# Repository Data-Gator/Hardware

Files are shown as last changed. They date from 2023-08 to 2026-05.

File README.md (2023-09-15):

# Hardware
Documents how to build and use Data Gator boards.

| Resource | Description |
| :---: | :---: |
| [Hardware Revision Design Files](./Hardware_Revisions/README.md) | Links to board design files for v1.4 and later. Contains electrical design schematics, BOMs, CAD, and assembly automation files. |
| [Sensors and Wiring Guides](./Sensors_And_Wiring/README.md) | Links to guides for using various supported sensors with the Data Gators. |
| [Board Fabrication and Assembly Guides](./Board_Assembly_Guides/README.md) | Documentation for self-assembly of surface mount and through-hole components for the Data Gators. |

## Hardware Overview

The images below show various components incorporated into the Data Gator carrier board design. 

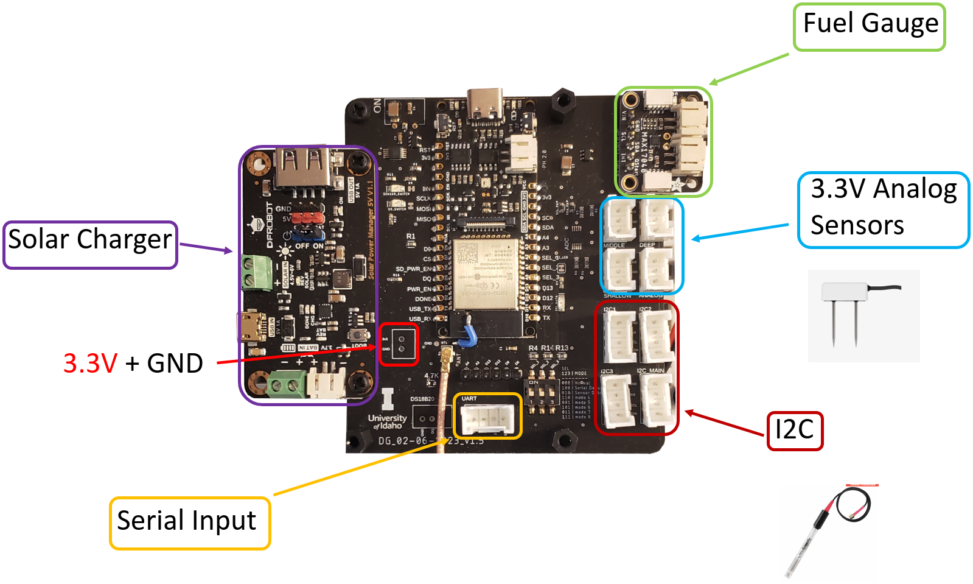
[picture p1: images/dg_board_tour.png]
board tour


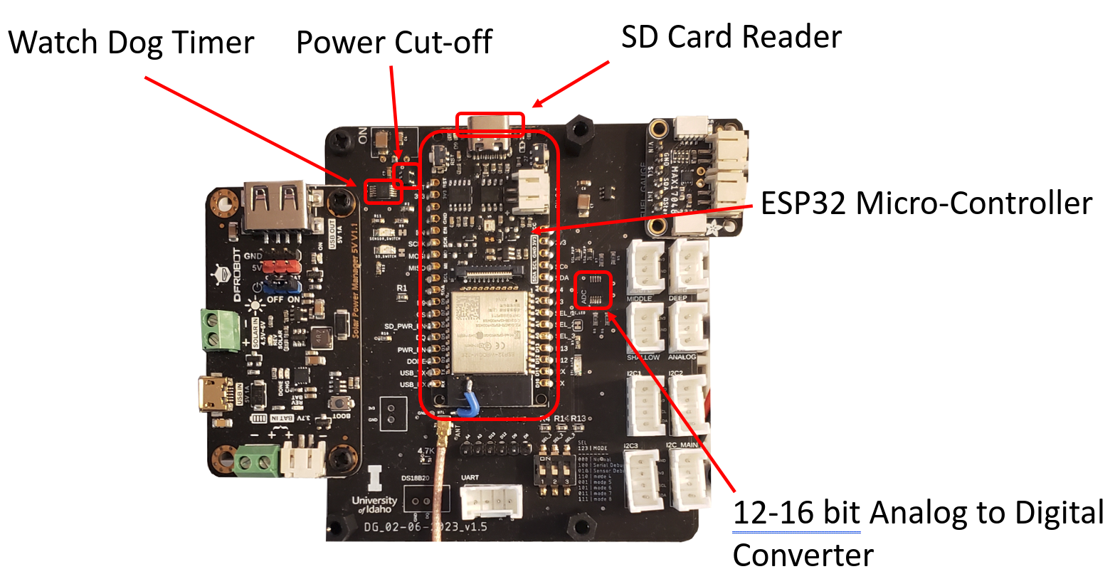
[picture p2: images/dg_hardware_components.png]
hardware comp


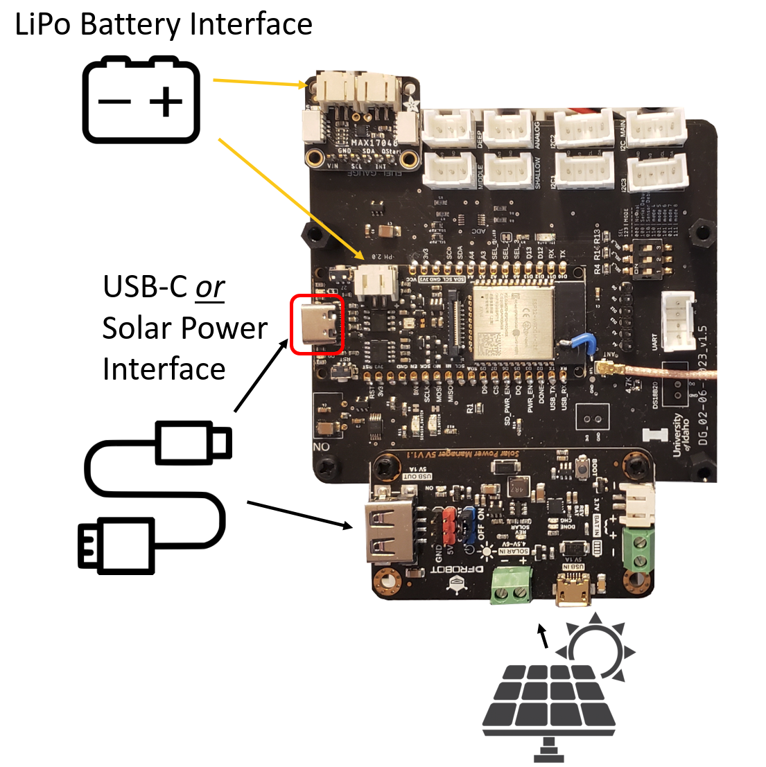
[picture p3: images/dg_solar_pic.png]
solar hookups


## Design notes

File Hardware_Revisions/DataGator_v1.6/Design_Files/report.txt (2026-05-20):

Info: Processing symbol 'R10:Resistor_SMD:R_0603_1608Metric'.
Info: Processing symbol 'C1:Capacitor_SMD:C_1210_3225Metric'.
Info: Processing symbol 'JP2:Connector_PinHeader_2.54mm:PinHeader_1x06_P2.54mm_Vertical'.
Info: Processing symbol 'JP3:'.
Info: Processing symbol 'JP4:Jumper:SolderJumper-2_P1.3mm_Open_RoundedPad1.0x1.5mm'.
Info: Processing symbol 'R1:Resistor_SMD:R_0603_1608Metric'.
Info: Processing symbol 'R2:Resistor_SMD:R_0603_1608Metric'.
Info: Processing symbol 'R3:Resistor_SMD:R_0603_1608Metric'.
Info: Processing symbol 'R4:Resistor_SMD:R_0603_1608Metric'.
Info: Processing symbol 'R5:Resistor_SMD:R_0603_1608Metric'.
Info: Processing symbol 'R6:Resistor_SMD:R_0603_1608Metric'.
Info: Processing symbol 'R7:Resistor_SMD:R_0603_1608Metric'.
Info: Processing symbol 'R8:Resistor_SMD:R_0603_1608Metric'.
Info: Processing symbol 'R9:Resistor_SMD:R_0603_1608Metric'.
Info: Processing symbol 'JP1:'.
Info: Processing symbol 'R11:Resistor_SMD:R_0603_1608Metric'.
Info: Processing symbol 'R12:Resistor_SMD:R_0603_1608Metric'.
Info: Processing symbol 'R13:Resistor_SMD:R_0603_1608Metric'.
Info: Processing symbol 'R14:'.
Info: Processing symbol 'R15:'.
Info: Processing symbol 'S1:MSS-102568-14A-90-D:SW_MSS-102568-14A-90-D'.
Info: Processing symbol 'S2:DS04_254_2_03BK_SMT:SW_DS04-254-2-03BK-SMT'.
Info: Processing symbol 'U1:footprints:SOT25_DIO'.
Info: Processing symbol 'U2:footprints:SOT25_DIO'.
Info: Processing symbol 'U3:TPL5000DGST:SOP50P490X110-10N'.
Info: Processing symbol 'U4:DFR0654:MODULE_DFR0654'.
Info: Processing symbol 'U5:ADS1015IDGST:SOP50P490X110-10N'.
Info: Processing symbol 'J8:533750310:MOLEX_533750310'.
Info: Processing symbol 'C2:Capacitor_SMD:C_0603_1608Metric'.
Info: Processing symbol 'C3:Capacitor_SMD:C_0603_1608Metric'.
Info: Processing symbol 'C4:Capacitor_SMD:C_0603_1608Metric'.
Info: Processing symbol 'C5:Capacitor_SMD:C_1210_3225Metric'.
Info: Processing symbol 'C6:Capacitor_SMD:C_0603_1608Metric'.
Info: Processing symbol 'D1:LED_SMD:LED_1206_3216Metric'.
Info: Processing symbol 'D2:LED_SMD:LED_1206_3216Metric'.
Info: Processing symbol 'J3:Connector_Coaxial:U.FL_Hirose_U.FL-R-SMT-1_Vertical'.
Info: Processing symbol 'J4:MEM2051-00-195-00-A_REVD1:GCT_MEM2051-00-195-00-A_REVD1'.
Info: Processing symbol 'J5:533750310:MOLEX_533750310'.
Info: Processing symbol 'J6:533750310:MOLEX_533750310'.
Info: Processing symbol 'J7:533750310:MOLEX_533750310'.
Info: Processing symbol 'J9:533750410:MOLEX_533750410'.
Info: Processing symbol 'J10:533750410:MOLEX_533750410'.
Info: Processing symbol 'J11:533750410:MOLEX_533750410'.
Info: Processing symbol 'J12:533750410:MOLEX_533750410'.
Info: Processing symbol 'J13:533750210:MOLEX_533750210'.
Info: Processing symbol 'J14:533750310:MOLEX_533750310'.
Info: Processing symbol 'J15:Connector_PinHeader_2.54mm:PinHeader_1x06_P2.54mm_Vertical'.
Info: Processing symbol 'J16:533750410:MOLEX_533750410'.
Add J16 (footprint '533750410:MOLEX_533750410').
Add J9 (footprint '533750410:MOLEX_533750410').
Add J10 (footprint '533750410:MOLEX_533750410').
Add J11 (footprint '533750410:MOLEX_533750410').
Add S1 (footprint 'MSS-102568-14A-90-D:SW_MSS-102568-14A-90-D').
Add J12 (footprint '533750410:MOLEX_533750410').

Info: Total warnings: 0, errors: 0.

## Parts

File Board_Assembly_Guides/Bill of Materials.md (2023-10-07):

# Bill Of Materials
## Surface Mount Devices (SMD)
This is a list of devices and quantities which should be purchased for building the Data Gator. PCB Fabrication companies may do the purchasing or use company stock.

| Name | Description | Quantity |Digikey/Mouser Part # | Link | 
| :---: | :---: | :---: | :---: | :---: |
| Resistor | 0603 100kOhm| 11 || https://www.digikey.com/en/products/detail/walsin-technology-corporation/WR06X104-JTL/13241355 |
| Ceramic Capacitor |10uF| 2 || https://www.digikey.com/en/products/detail/samsung-electro-mechanics/CL32A106MOJNNNE/3888522 |
| Resistor | 0603 2kOhm| 3 || https://www.digikey.com/en/products/detail/yageo/RC0603FR-072KL/727009 | 
| Resistor | 0603 5kOhm| 2 || https://www.digikey.com/en/products/detail/yageo/RT0603BRE075KL/7708365 | 
| Resistor | 0603 4.7kOhm | 2 || https://www.digikey.com/en/products/detail/yageo/RC0603FR-074K7L/727212 | 
| Micro-SD Card Holder | 9 Position, Push-Push, Right Angle | 1 || https://www.digikey.com/en/products/detail/gct/MEM2051-00-195-00-A/10460360?s=N4IgTCBcDaILIFE5gAwFYCMIC6BfIA | 
| u.FL SMT| 50 Ohm | 1 || https://www.digikey.com/en/products/detail/hirose-electric-co-ltd/U-FL-R-SMT-1-40/4285474 | 
| DIP Switch | SPST, 2.54mm, 3 position |1 || https://www.digikey.com/en/products/detail/cui-devices/DS04-254-2-03BK-SMT/11310920 |
| ADS1015 (Analog-to-Digital Converter) | 12 bit, IDGST, 10VSSOP package| 1 || https://www.digikey.com/en/products/detail/texas-instruments/ADS1015IDGST/2174980 | 
| AP2171WG | IC Power Switch, P-Channel, SOT25 package|2|| https://www.digikey.com/en/products/detail/diodes-incorporated/AP2171WG-7/1964664 | 
| TPL5000| Watch Dog Timer, 10VSSOP package|1|| https://www.digikey.com/en/products/detail/texas-instruments/TPL5000DGST/4331549 | 
| Red LED | 1206, 20mA, 1.7V|3|| https://www.mouser.com/ProductDetail/Stanley-Electric/BR1101W-TR?qs=byeeYqUIh0Pp62ktTXSSvA%3D%3D |
| Ceramic Capacitor | 0603, 0.1uF|4|| https://www.mouser.com/ProductDetail/KEMET/C0603C104K5RAC3121?qs=oBCMsStVSxe1EkGyoyETtg%3D%3D |
# Through-Hole Components
These components, as well as the daughter boards, must be soldered or attached to the Data Gator.

| Name | Description | Quantity | Digikey/Mouser Part # | Link | 
| :---: | :---: | :---: | :---: | :---:|
| WDT Switch | SPDT slide switch, 1.4mm | 1 || https://www.digikey.com/en/products/detail/cui-devices/MSS-102568-14A-90-D/13978973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 |
| 6-pin header| 6 pin header, 2.54mm pitch | 1 || https://www.digikey.com/en/products/detail/adam-tech/PH1-06-UA/9830394 | 

# Daughter Boards

| Name | Description | Quantity | Digikey/Mouser Part # | Link | 
| :---: | :---: | :---: | :---: | :---: |
| Firebeetle3 ESP32-E | Espressif ESP-WROOM-32E based micro-controller board with USB interface and GPIO accessible through castellated vias. |1| | https://www.dfrobot.com/product-2195.html |
| Adafruit MAX17048 Fuel Gauge | LiPoly / LiIon Battery Monitor/Fuel Gauge |1| | https://www.adafruit.com/product/5580 | 
| DFRobot Solar Power Manager 5V | Manages solar charging for 5V LiPoly batteries. | 1| | https://www.dfrobot.com/product-1712.html |

# Connectors
Connectors must be soldered by hand since they are through-hole components. These are used to connect analog and I2C sensors to the board. Both sensor options are viable and represent two different price points. Buying 15 sets of connectors in February 2023, JST connectors cost $67 dollars total while Molex connectors cost $125.
### Molex Connectors
The premium option, likely more resistant to  physical damage and support more force if sensor wires get  pulled.

| Item | Quantity | Link | 
| :---: | :---: | :---: |
| 2 Pin Housing Receptacle, 2.5mm | 1 | https://www.digikey.com/en/products/detail/molex/0511030200/2405316
| 3 Pin Housing Receptacle, 2.5mm| 4 | https://www.digikey.com/en/products/detail/molex/0511030300/2405314
| 4 Pin Housing Receptacle, 2.5mm | 4| https://www.digikey.com/en/products/detail/molex/0511030400/2405335
| Socket Contact, 22-28 AWG Crimp | 30 | https://www.digikey.com/en/products/detail/molex/0503518000/2404938
| 2 Pin Connector Header, 2.5mm | 1 | https://www.digikey.com/en/products/detail/molex/0533750210/2405348
| 3 Pin Connector Header, 2.5mm | 4 | https://www.digikey.com/en/products/detail/molex/0533750310/3263194
| 4 Pin Connector Header, 2.5mm | 4 | https://www.digikey.com/en/products/detail/molex/0533750410/2421210

### JST Connectors

Cheaper than Molex connectors and functionally equivalent. The connection made is looser and may be more prone to failure under physical stress such as pulling.

| Item | Quantity | Link | 
| :---: | :---: | :---: |
| 2 Pin Connector Header, 2.5mm| 1 | https://www.digikey.com/en/products/detail/jst-sales-america-inc/B02B-XASK-1-LF-SN/1634730
| 3 Pin Connector Header, 2.5mm | 4 | https://www.digikey.com/en/products/detail/jst-sales-america-inc/B03B-XASK-1-LF-SN/1634731
| 4 Pin Connector Header, 2.5mm | 4 | https://www.digikey.com/en/products/detail/jst-sales-america-inc/B04B-XASK-1-LF-SN/1634735
| Socket Contact, 22-28 AWG Crimp | 30 | https://www.digikey.com/en/products/detail/jst-sales-america-inc/SXA-001T-P0-6/923775
| 2 Pin Connector Header, 2.5mm | 1 | https://www.digikey.com/en/products/detail/jst-sales-america-inc/XAP-02V-1/923774
| 3 Pin Housing Receptacle, 2.5mm | 4 | https://www.digikey.com/en/products/detail/jst-sales-america-inc/XARP-03V/7423921
| 4 Pin Housing Receptacle, 2.5mm | 4 | https://www.digikey.com/en/products/detail/jst-sales-america-inc/XAP-04V-1/959010

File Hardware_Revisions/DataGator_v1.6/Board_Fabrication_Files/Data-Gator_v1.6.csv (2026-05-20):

Id | Designator | Footprint | Quantity | Designation | Supplier and ref
1 | C3 | C_1210_3225Metric | 1 | 10uF
2 | C4, C5, C6 | C_0603_1608Metric | 3 | 0.1uF
3 | D2 | LED_1206_3216Metric | 1 | SENSOR_SWITCH_LED
4 | J2, J3, J4, J5, J13 | MOLEX_533750410 | 5 | 533750410
5 | J6, J7 | MOLEX_533750210 | 2 | 533750210
6 | J8, J9, J10, J11 | MOLEX_533750310 | 4 | 533750310
7 | J12 | U.FL_Hirose_U.FL-R-SMT-1_Vertical | 1 | u.FL
8 | J14 | PinHeader_1x06_P2.54mm_Vertical | 1 | Brk_Out_HDR
9 | J15 | PinHeader_1x06_P2.54mm_Vertical | 1 | Fuel Gauge
10 | J16, J17 | SolderWirePad_1x01_SMD_1x2mm | 2 | Conn_01x01
11 | R3, R7, R8, R9, R10, R11, R12, R13, R14, R15 | R_0603_1608Metric | 10 | 100K
12 | R4 | R_0603_1608Metric | 1 | 2.0K
13 | R16, R17 | R_0603_1608Metric | 2 | 5K
14 | S1 | SW_MSS-102568-14A-90-D | 1 | MSS-102568-14A-90-D
15 | S2 | SW_DS04-254-2-03BK-SMT | 1 | DS04-254-2-03BK-SMT
16 | U2 | SOT25_DIO | 1 | AP2171WG-7
17 | U3 | SOP50P490X110-10N | 1 | ADS1015IDGST
18 | U4 | SOP50P490X110-10N | 1 | TPL5000DGST
19 | U5 | MODULE_DFR0654 | 1 | DFR0654

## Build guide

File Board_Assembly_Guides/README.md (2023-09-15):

# Board Fabrication and Assembly Guide for Data Gators

All the information below is meant to guide _anybody_ through the process and various methods available for making your own Data Gator board. 

#### Table of Contents

| Link | Description |
| :---: | :---: |
| [Overview](#overview)| Enumerates the basic steps for having a board manufactured and then assembling it. |
| [Terms and Definitions](#terms-and-definitions) | Terms used in these guides to describe the process of producing fully functional Data Gators. |
| [Fabrication](./PCB_Fabrication_Guide.md) | Guide with steps for ordering PCBs from several 3rd party fab houses. |
| [Assembly](./PCB_Assembly_Guide.md) | Guide for the process of assembling surface mount components. |
| [Through-Hole Assembly](./PCB_Through-hole_Guide.md) |  Guide for soldering through-hole components. |
| [Adding Final Boards and Enclosures](./Enclosure_Build_Guide.md) | Links and guide for assembling an enclosure for your Data Gator board. |

#### Overview

1. _**optional** modify [schematics and designs](https://github.com/Data-Gator/Hardware/tree/main/Hardware_Revisions)_
2. [Have PCBs Fabricated](#how-to-acquire-data-gator-pcbs)
3. [Assemble PCBs](#how-to-assemble-the-pcbs)

    * Apply solder paste.
    * Place components.
    * Use hot plate/reflow oven/soldering iron to solder components.
    * Check components for bridges with magnifying glass and rework with soldering iron to remove bridges.

4. Solder through-hole components.
5. Connect separate boards and make cables.

    * Add solar power manager
    * Add battery fuel gauge

6. _**optional** apply antenna mod for external antenna_

#### Terms and Definitions

A few terms are defined below to hopefully make this more readable for those with minimal prior experience. If you have questions and would like to see this guide expanded in some way, please create an issue for the repository and ask away!

| Term | Definition |
| :---: | :---: |
| Fabrication | Refers to having a printed circuit board (PCB) manufactured without components, simply a layered board with vias and pads for components. Not something you should attempt yourself, this part of the process must be contracted through a third-party fab house. |
| Assembly | Refers to the process of installing components (surface mount and through-hole) on the PCB. Surface mount components often require more knowledge or special equipment to solder while through-hole components can usually be soldered with just a soldering iron and solder! This guide addresses some methods for those without the optimal equipment to get the job done with some simple and not too unusual tools that can be acquired cheaply. | 
| Reflow | Heating up solder to the point that it "flows" to form a solder joint between the component and the board pad. |

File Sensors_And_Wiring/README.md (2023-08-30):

# Sensor Documentation and Wiring

This directory contains information on how to wire and use sensors which are currently supported by the aggregator board. Below is a list of the sensors that are documented here and the date they were added to documentation.

### Documented Sensors

| Sensor | Description | Date Added |
| :---: |:---: | :---: |
| [Meter Teros 10](Meter_Teros_10_Analog/README.md) | Volumetric Water Content(VWC)(Analog) | 03/10/2023 |
| [Atlas Gravity pH](Atlas_Gravity_pH_Analog/README.md) | Soil pH Sensor(Analog) | 03/10/2023 | 
| [Atlas EZO-pH](Atlas_EZO-pH_UART_I2C) | Soil pH Sensor(UART/I2C) | 03/10/2023 | 
| [KKM K6P](KKM_K6P_BLE) | Temperature and Humidity Sensor(BLE) | 03/10/2023 |

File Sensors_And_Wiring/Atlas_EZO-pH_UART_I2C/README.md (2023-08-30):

# Atlas EZO-pH Sensor (UART/I2C)

| Resource | Contents |
| :---: | :---: |
| [Purchase Link](https://atlas-scientific.com/kits/ph-kit/#) | Pricing, specs, and links to documentation |
| [Datasheet](https://files.atlas-scientific.com/pH_EZO_Datasheet.pdf) | Documentation of wiring and usage in UART/I2C mode |

#### EZO-pH Module
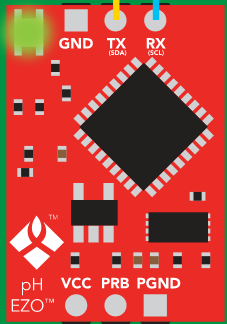
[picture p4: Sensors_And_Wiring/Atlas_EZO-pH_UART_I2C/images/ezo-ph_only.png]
ezo ph without carrier board

#### EZO-pH Module on Carrier Board (top view)
Note that the pin labels on the bottom of the carrier board(purple) correspond to the I2C mode pin mapping. 
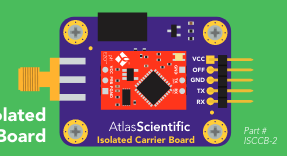
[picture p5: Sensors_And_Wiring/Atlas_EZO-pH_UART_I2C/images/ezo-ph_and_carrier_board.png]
ezo_ph with carrier board


## Usage

By default this sensor is factory configured to operate in UART mode. This is great because it allows the user to interface with the sensor using a laptop or other PC using a USB-to-Serial converter, often an FTDI cable.

However, in cases where multiple sensors are needed or for embedded applications it is more helpful to calibrate and configure the sensor's parameters in UART mode and then change to I2C mode for use with an embedded system like the Data Gator.

The steps for this process are listed below:

1. Connect sensor to PC using FTDI cable.
2. Calibrate and configure sensor using the serial interface.
3. Set sensor to  I2C mode and configure address as needed.
4. Connect sensor to DG and use!

Instructions for each of these steps will be included below.

### Connecting to Sensor via FTDI Cable 

FTDI cables will have a USB connector on one end while the other end will have jumper connectors to interface between the FTDI chip and the sensor or micro-controller. The connection table lists which wires should be connected between the sensor carrier board and the FTDI cable.

#### FTDI-to-EZO-pH Connection Table

| FTDI | EZO-pH Carrier Board | 
| :---: | :---: |
| GND | GND | 
| CTS | Not Connected(NC) | 
| VCC(or 5V from USB) | VCC | 
| TXD | RX | 
| RXD | TX | 
| DTA | NC | 

###### NOTE
It is important that the TXD of the FTDI be connected to the RX of the EZO-pH board and vice a versa for the RXD and TX pins. If TXD is connected to TX and RXD to RX, no data will be transmitted to or from the board.

#### Opening Serial Interface on PC
There are a few serial monitor options available, but since this project is built and maintained with PlatformIO, these instructions will use the built-in serial monitor.

To open the serial monitor enter the following command in your terminal(or the visual studio code terminal):

    pio device monitor -b 9600

This will open a serial monitor running at 9600 baud, the default baud rate of the sensor. 

If you notice all data is being printed on one line, try using the command below to modify the newline character of the terminal.

    pio device monitor -b 9600 --eol CR

This has been observed to work better in some cases because the carriage return character is the command and data transmission terminator used by the EZO-pH module whereas the default line terminator in the PlatformIO serial monitor is CRLF(carriage return followed by a line feed).

The default sensor read setting in UART mode is continuous mode, which means that readings are continuously taken from the sensor and printed to the serial interface. To make sure this is happening:

1. Check that the module is powered on. If so, the LED should be blinking green and blue. If not, the module is not powered on so check wiring and USB connection.
2. Verify that the TXD and RXD lines are properly wired. If they are, you should see a pH value printed to the serial monitor every couple of seconds.

###### If you see nothing or gibberish printed to the terminal, but the LED on the module is ON
Check to make sure your TXD and RXD lines are wired correctly, maybe try swapping them.

### Calibrating Sensor via Serial Interface 

Once you have a serial monitor open and are receiving data from the device, you should be able to use the commands defined by Atlas Scientific for controlling the device. These are well documented in the datasheet linked at the top of this guide.

As stated by the documentation, the process for calibrating the module is as follows: 

1. Read the 7.0 pH buffer with the sensor. Once the readings have stabilized enter the command `Cal, mid, <pH_reading_here>` and press enter to submit the command with a carriage return. If successful, the sensor module should respond by printing `*OK` to the monitor.

    * _**Note:**_ Sending the midpoint calibration command(above) clears all other calibration data on the chip. This is because calibrating the midpoint equates to a single point calibration.

2. Read the 4.0 pH buffer. Then enter `Cal, low, <pH_reading_here>`.
3. Finally read the 10.0 pH buffer and calibrate with `Cal, high, <pH_reading_here>`.

Once those commands are executed, the calibration status of the sensor can be queried with `Cal,?` which will return `?Cal,0` if not calibrated, or `?Cal,<number_1-3>` to indicate calibration with however calibration points were used.

### Set Sensor to I2C Mode and Configuring Address
Use command 
    
    `I2C,<i2c_addr_here>` 

to set I2C address and reboot in I2C mode. After rebooting the LED should remain blue to indicate that it is operating in I2C mode.

The I2C address should be chosen from three possible values, `0x01`, `0x02`, or `0x03`. No more than one pH sensor with the same address may be connected to the same aggregator at a time, and the address assigned should correspond to the relative depth that the sensor is buried at with `0x01` being the most shallow.

### Wiring to DGv1.5+

Below is the connection table for the EZO-pH carrier board when in I2C mode. 

#### EZO-pH-to-I2C Connection Table

| Atlas EZO-pH (top label) | Atlas EZO-pH (bottom label) | Aggregator | 
| :---: | :---: | :---: |
| VCC | VCC | 3v3 | 
| OFF | OFF | NC | 
| GND | GND | GND | 
| TX | SDA | SDA | 
| RX | SCL | SCL |

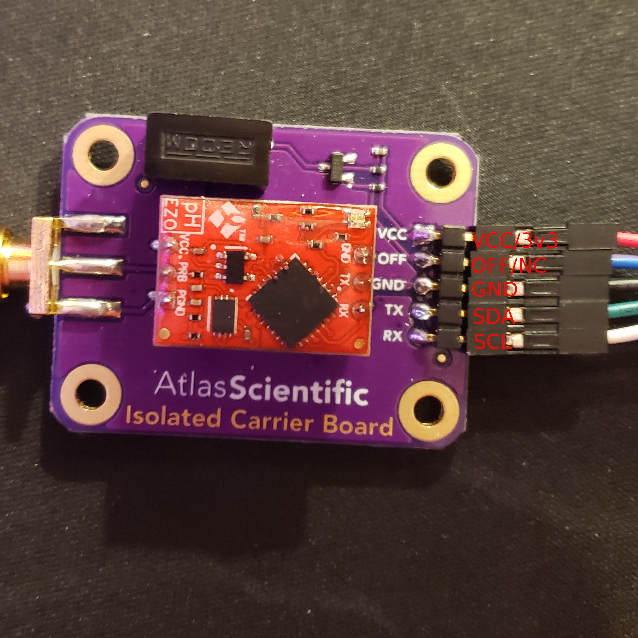
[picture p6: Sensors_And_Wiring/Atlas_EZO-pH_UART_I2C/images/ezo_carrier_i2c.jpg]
ezo pH carrier to connector

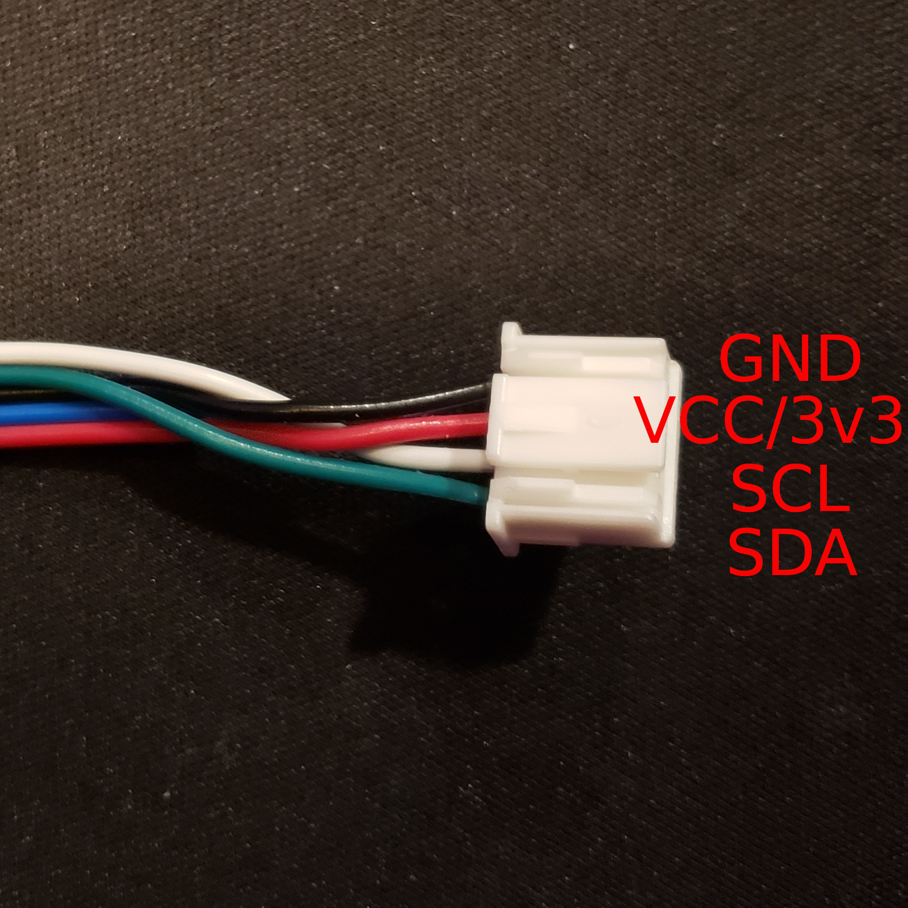
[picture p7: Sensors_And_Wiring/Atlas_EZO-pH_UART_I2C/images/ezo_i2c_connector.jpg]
ezo connector i2c


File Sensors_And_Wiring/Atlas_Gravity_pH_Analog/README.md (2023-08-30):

# Atlas Gravity pH Sensor (Analog)

| Resource | Contents | 
| :---: | :---: |
| [Purchase Link](https://atlas-scientific.com/kits/gravity-analog-ph-kit/) | Atlas Scientific storefront link, page also contains documentation links and specs | 
| [Datasheet](https://files.atlas-scientific.com/Gravity-pH-datasheet.pdf) | Documentation on operation, specs, and wiring diagrams | 

### Wiring Diagram

The pictures below show the wiring of the jumper wires between the sensor and the 3 pin connector which is used to connect to the analog ports on the aggregator board, hardware version 1.5 and later.

#### Connection Chart
| Gravity pH | Aggregator |
| :---: | :---: |
| `-` | GND | 
| `+` | 3v3 | 
| `A` | SIG | 

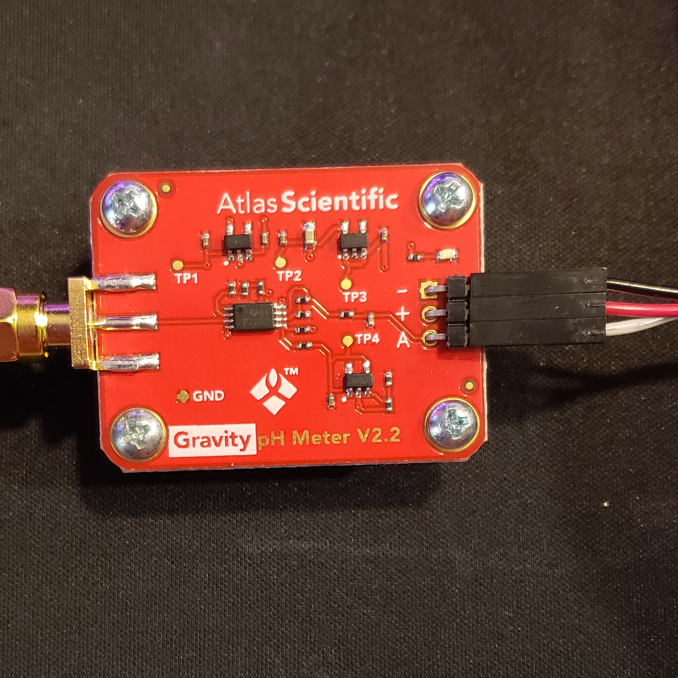
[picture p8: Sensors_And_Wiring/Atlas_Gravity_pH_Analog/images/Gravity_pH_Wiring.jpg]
board to connector wiring


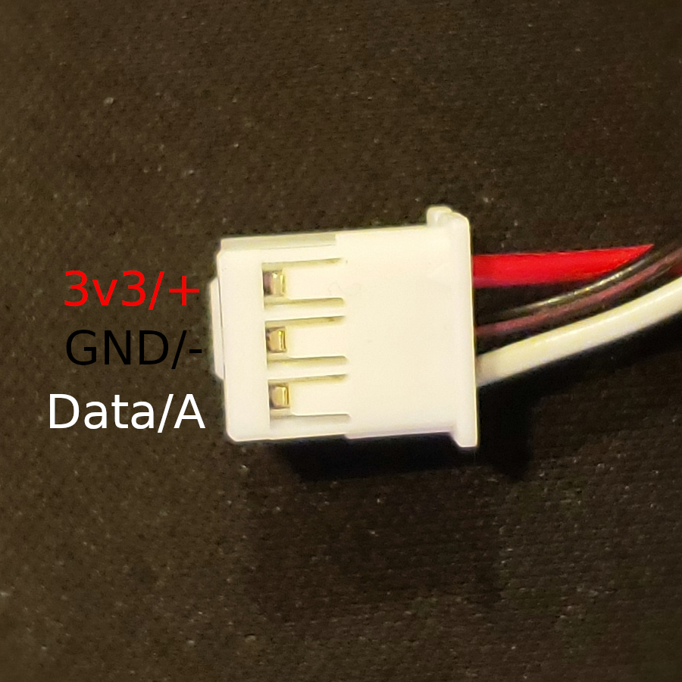
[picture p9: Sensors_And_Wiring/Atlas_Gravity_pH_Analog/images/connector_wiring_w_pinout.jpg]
connector to aggregator wiring


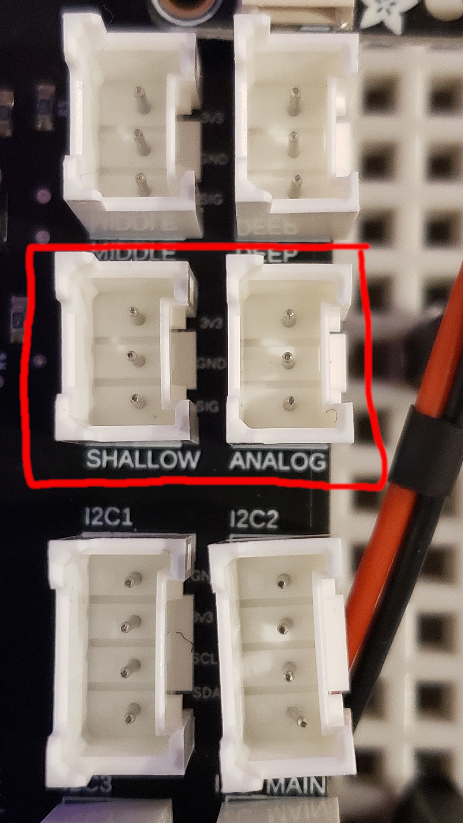
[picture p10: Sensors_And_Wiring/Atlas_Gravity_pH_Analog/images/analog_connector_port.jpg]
aggregator connector


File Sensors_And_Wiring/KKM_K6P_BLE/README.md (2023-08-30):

# KKM K6P Sensor (BLE)

This sensor has no external wiring. It does however have a few helpful resources for working with it.

| Resource | Contents |
| :---: | :---: |
| [Purchase Link](https://www.alibaba.com/product-detail/KKM-K6P-bluetooth-ibeacon-Ble-5_1600289289878.html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) | Link to buy sensors, ask questions through online storefront |
| [KBeaconPro](https://play.google.com/store/apps/details?id=com.beacon.kbeaconsetpro&gl=US) | App for configuring and testing KKM sensors, can be used to connect to sensors and download data |

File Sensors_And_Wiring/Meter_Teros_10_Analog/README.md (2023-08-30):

# Meter Teros 10 VWC Sensor (Analog)

| Resource | Contents | 
| :--: | :---: |
| [Purchase Link](https://www.metergroup.com/en/meter-environment/products/teros-10-soil-moisture-sensor) | Quote request, specs, and company contacts | 
| [Datasheet](https://publications.metergroup.com/Manuals/20788_TEROS10_Manual_Web.pdf) | Installation and wiring instructions, calibration for soils, and specifications | 

### Wiring Diagram
See chart and pictures below for wiring this sensor to the aggregator board. Supported for versions 1.4+.

#### Connection Chart
| Meter Teros 10 | Aggregator | 
| :---: | :---: |
| Brown(Power) | 3v3 | 
| Bare(GND) | GND | 
| Orange(Data) | SIG |

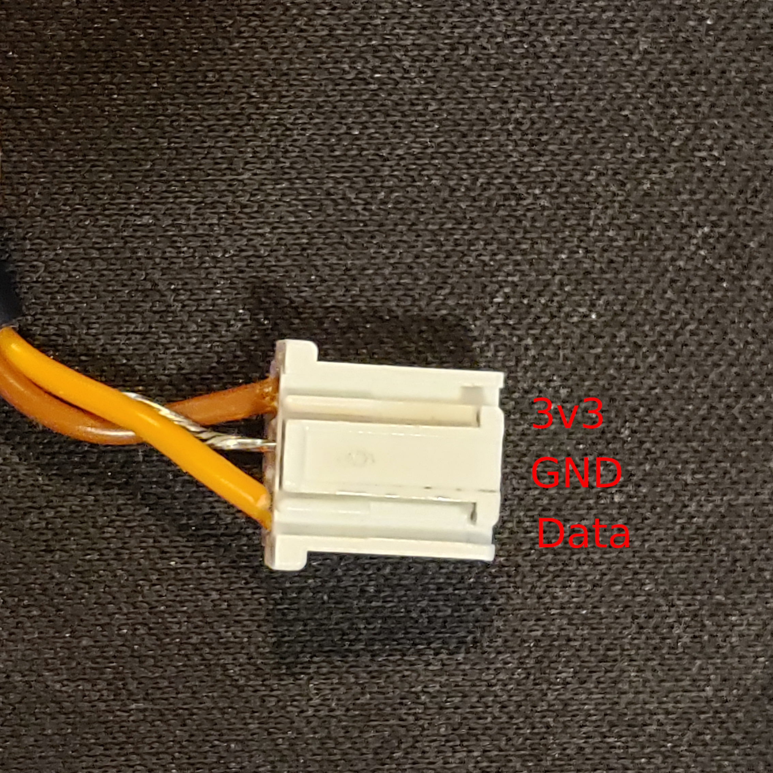
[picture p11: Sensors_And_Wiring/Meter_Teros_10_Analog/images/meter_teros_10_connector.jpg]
meter teros wire ends in connector


aggregator port

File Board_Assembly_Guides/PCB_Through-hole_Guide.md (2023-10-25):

# Through-Hole Guide
board tour

Above is a map of the various components on the Data Gator. The following are through hole components that generally must be soldered:

1. Fuel Gauge
2. 3.3V Analog Sensors
3. I2C ports

Each of these components are simple to attach using the picture above as an orientation guide.

>[!note]
>The analog and I2C ports have a plastic alignment pin on the bottom which must be trimmed off before soldering to the board. A good tool for this is a pair of flush cutters.

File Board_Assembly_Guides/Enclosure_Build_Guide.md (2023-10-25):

# Enclosure Build Guide
Below is a picture of the weather proof enclosure built for test installations of the Data Gators. 

![[exterior_ortho.jpg]]
![[enclosure_topdown.jpg]]

Below is a list of the components used in our box build:

| Component | Cost | 
| :---: | :---: |
| [Qilipsu Box](https://www.amazon.com/dp/B085QCT543?ref=ppx_pop_mob_ap_share&th=1) | $26.99 | 
| [Qilipsu Cable Gland](https://www.amazon.com/dp/B07ZRH3V59?ref=ppx_pop_mob_ap_share) | $10.99 | 
| [u.FL to SMA Adapter](https://www.amazon.com/dp/B07H3P9KDQ?ref=ppx_pop_mob_ap_share) | $10.99 |
| [JST PH Connector Kit](https://www.amazon.com/gp/product/B097BVPB38/ref=ewc_pr_img_2?smid=A2WB8VY980GP2P&psc=1) | $9.79 | 
| [WiFi Antenna](https://www.amazon.com/dp/B07TTY8W2Y?ref_=cm_sw_r_cp_ud_dp_9A5KHG0H4P9HB2RVQRNM)| $7.99 |

This places the cost of building an enclosure at around $60 dollars.

# Build Procedure
1. Mount Data Gator to mounting plate. Hexagonal plastic standoffs with M3 threading were used to mount the Data Gator in the example above. To connect the standoffs to the mounting plate 1/4" holes were drilled into the plate and then super glue was used to secure the standoffs in the holes. Note that fast setting glue is recommended for this process.
2. Next mount the u.FL to SMA adapter by drilling another hole in the side of the box. Use the mounting hardware (lock rings and nut) to mount the SMA adapter in the hole. For waterproofing, applying a silicone caulk is recommended.
3. To mount the battery, adhesive velcro was used and placed on the wall of the box.
4. Finally, mount the cable glands by drilling holes in the side of the box. We found a step drill bit to be the fastest and most effective way of doing this. Other methods tend to be messy.

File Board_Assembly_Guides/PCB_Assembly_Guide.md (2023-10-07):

# PCB Assembly Guide for Data Gators
Read on for instructions for how to assemble an Data Gator board and example pictures of the finished product.

##### Prerequisites
1. Should have DG PCBs. Instructions for getting boards in [[PCB_Fabrication_Guide|PCB Fabrication Guide]].
2. All surface mount components should be installed.
3. All through-hole components from the [[Bill of Materials]].
4. Have all tools or alternatives listed in the [[PCB_Assembly_Guide#Equipment|equipment list]].

## Equipment

> [!note] 
> The following equipment is recommended for this project, but no specific brands/varieties are required. Example products are linked for quick reference.

| Item | Description | Example Link |
| :---: | :---: | :---: |
| Soldering Iron | Need a soldering iron with a moderately small tip. | [soldering iron search on adafruit](https://www.adafruit.com/search?q=soldering+iron) |
| Solder | Any solder wire will do, but thickness around **0.8mm or less** is recommended. | [solder wire options](https://www.amazon.com/s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) 
| Solder Wick (optional) | Solder wick is a fallback option when things go wrong. Even if you don't need it now, you likely will later. | [solder wick](https://www.amazon.com/s?k=solder+wick&crid=VG3VQ2B8YPI8&sprefix=solder+wick%2Caps%2C141&ref=nb_sb_noss_1) 
| Solder Pump (optional) | Like solder wick, this is essential for fixing mistakes and clearing solder out of through holes and vias. | [solder pump - kotto](https://www.amazon.com/Solder-Sucker-Desoldering-Removal-Soldering/dp/B08FDY2SGS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), [solder pump - engineer](https://www.amazon.com/Engineer-SS-02-Solder-Sucker/dp/B002MJMXD4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)
| Tweezers | Good for holding small components while soldering to save your fingers. | [ifixit tweezers set](https://www.amazon.com/iFixit-Precision-Tweezers-Set-Angled/dp/B079K874CQ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)
| Flush Cutters | Good for rework and clean up. | [hakko flush cutters](https://www.amazon.com/Hakko-CHP-170-Micro-Cutter/dp/B00FZPDG1K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)
| Third Hand and/or Vice (optional) | Something to hold your work is not mandatory - necessity is the mother of invention after all - but this may save you significant head ache. | [helping hands - kotto](https://www.amazon.com/Helping-Soldering-Workshop-Non-slip-Weighted/dp/B07MDKXNPC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)

## Instructions

##### Initial PCB + SMD Components
pcb unpopulated

1. Solder Firebeetle ESP32 micro-controller (uC) to PCB.

	pcb with firebeetle

> [!note] 
> **Tips for Alignment**
> It can be difficult to align the micro-controller board with the PCB pads for soldering and keep them aligned. To avoid misalignment, use the pin headers included with the micro-controller to align holes by placing the micro-controller on the PCB, aligning with holes, then placing the pin header through the holes. You can then solder the first and last hole of a side to keep the board in place, remove the pin header, and finish soldering both sides.

2. Solder switch to PCB. 
	soldered switch

3. Solder Fuel Guage to PCB.

	soldered switch

4. Solder analog and I2C plugs.

> [!note] 
> **Removing Alignment Pin**
> The plugs may come with an alignment pin on the bottom of the plug as can be seen in the picture below. Since the PCB has no alignment hole, this pin must be removed using a pair of flush cutters before soldering.
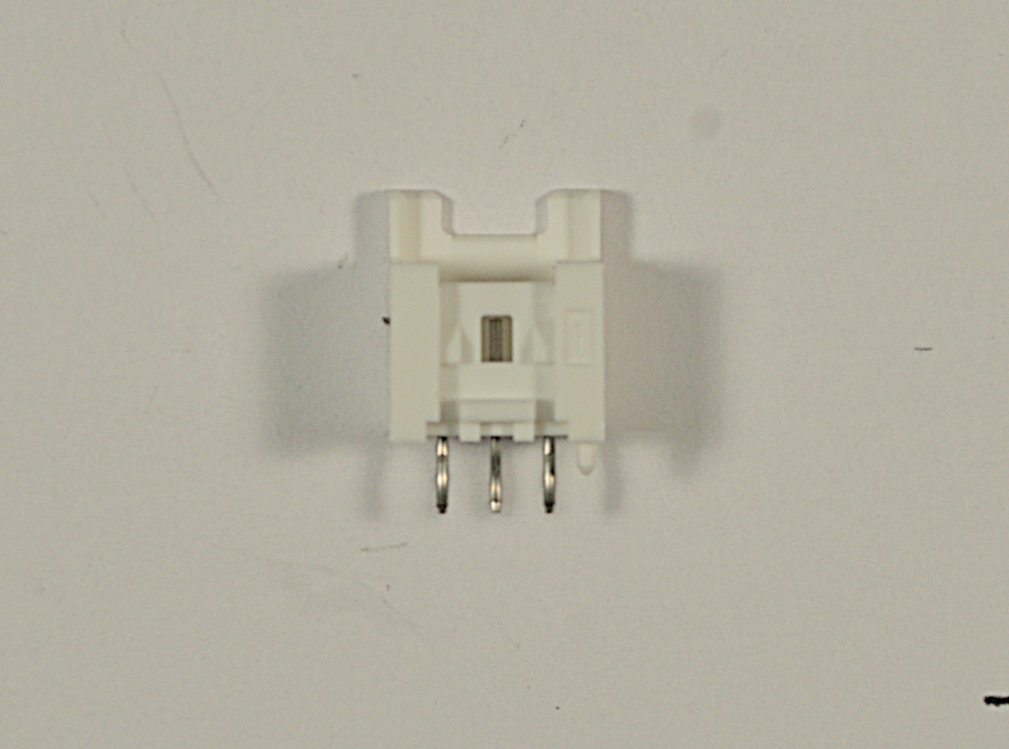
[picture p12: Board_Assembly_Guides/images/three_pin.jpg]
three pin
> 

pcb populated

5. Attach Solar Manager with M3 bolts.
6. Make battery/charging cable using instructions from [[crimping guide]].
7. _Optional: perform antenna mod following directions [in the antenna modification guide](https://community.home-assistant.io/t/how-to-add-an-external-antenna-to-an-esp-board/131601)_

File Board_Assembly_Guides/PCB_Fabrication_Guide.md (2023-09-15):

# PCB Fabrication Guide

This guide describes how to have a printed circuit board made. This almost universally must be accomplished by ordering a small run of boards to be manufactured and shipped to you. 

PCB fabrication equipment is expensive so it may help to follow the steps below to order PCB fabrication from a 3rd party vendor unless you have your own stuff.

## Ordering from [JLCPCB](https://jlcpcb.com/) and [PCBWay](https://www.pcbway.com/) and [Osh Park](https://oshpark.com/)

All three companies provide similar services including:

1. Online automated quotes based on: board quantity, size, and materials.
2. Add-on services: PCB assembly, stencil fabrication, etc.

#### Vendor Experience

These options allow a lot of flexibility, an accommodate all the requirements of getting the Data Gator boards made. Experience with each company might vary slightly. For example, I experienced:

* slower fabrication and shipping times with Osh Park (up to a week longer) whereas JLCPCB has a turn around of less than two weeks, ideal for prototyping.
* JLCPCB assembly services were buggy as of August, 2023, preventing double sided SMD component assembly.
* PCBWay provided good assembly and board fabrication, slightly lower mask quality than the other two and a fair amount of engineer interaction for assembly process (a good thing for working through issues).

Osh Park has the advantage of being based in the USA and offers various tiers of production speed, which may appeal if working on a government project.

### JLCPCB Steps (Can use for the others as well!)

In most cases to fabricate the board, you will upload the board as a Gerber file through the link on the manufacturer's website using the links above. Data Gator PCB Gerber files can be found by navigating to [hardware revisions](../Hardware_Revisions/README.md).

1. Navigate to site.
2. Upload Gerber using site link. Click Upload Gerber -> select zipped gerber file.

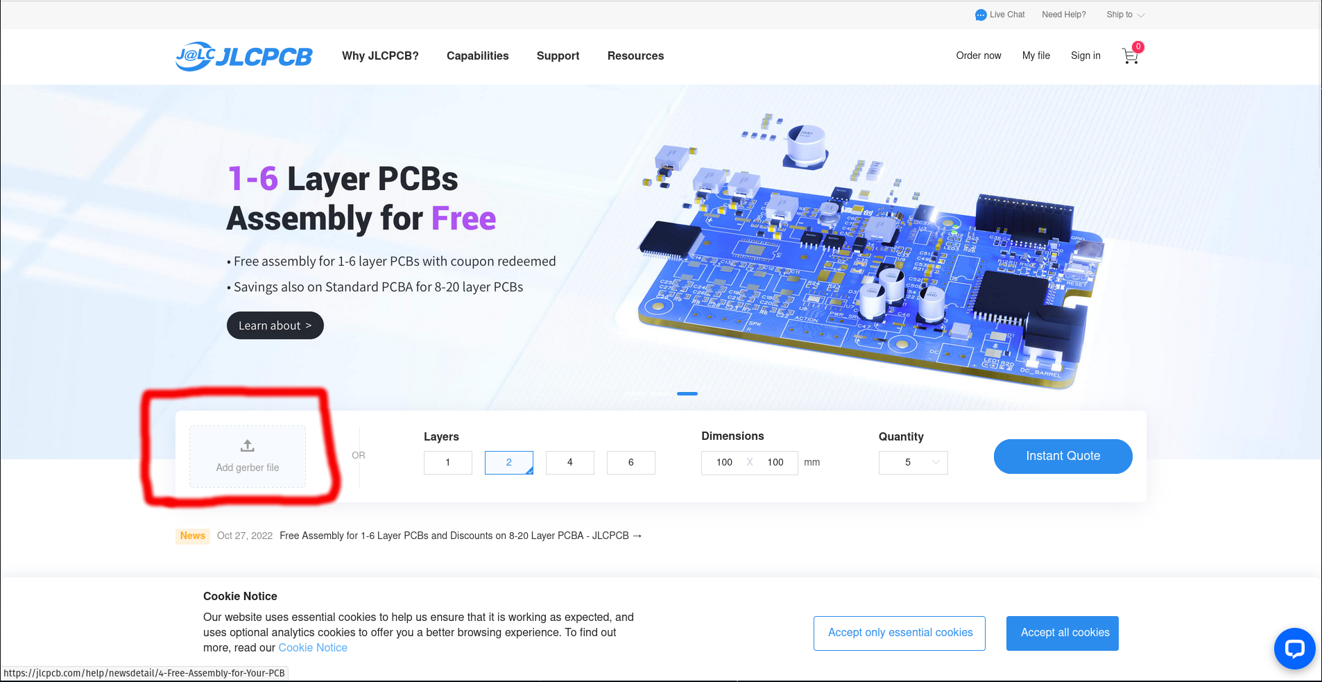
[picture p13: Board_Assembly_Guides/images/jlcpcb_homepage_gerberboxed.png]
gerber upload jlcpcb
    

3. Use configuration menu pictured below to set preferences for board fabrication. _**Note:**_ default options are sufficient, though the options used for this project are provided in the screenshot below if you wish to check.
    
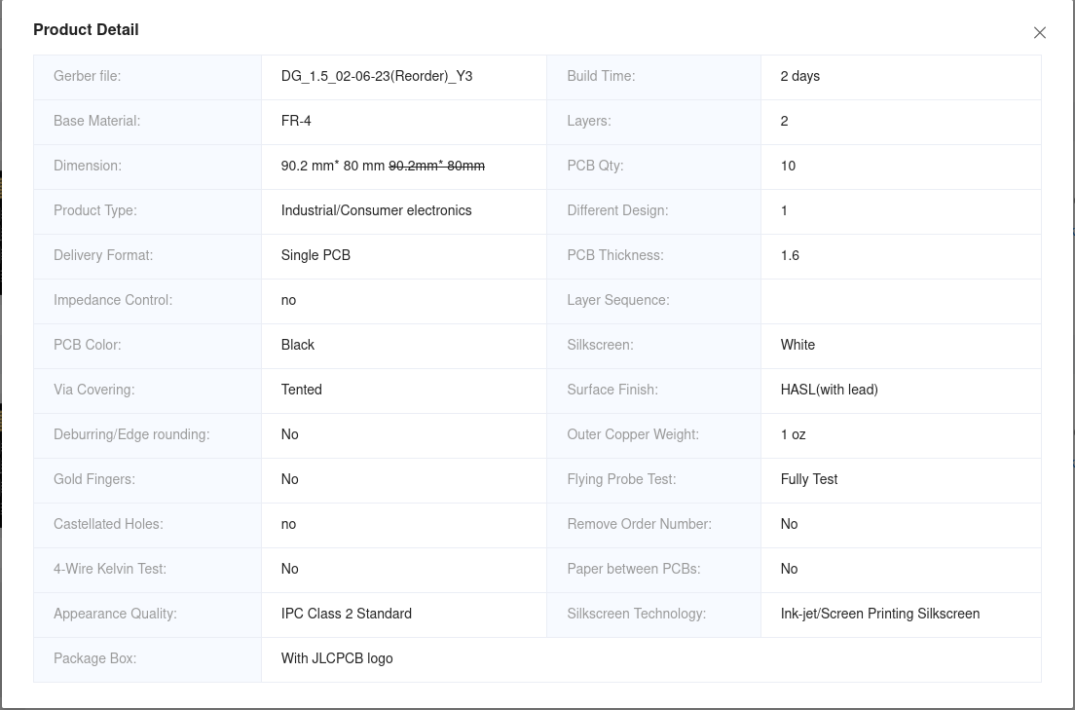
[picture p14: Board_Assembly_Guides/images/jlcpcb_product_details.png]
jlcpcb product details
    

4. Choose add-on services. _**Note:**_ the selected options are defaults from the site and may need to be changed based on your equipment and usage and are not meant to be copied.

    * if you have a [stencil printer](https://www.amazon.com/s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), you will likely want to select the framework option for the stencil as this means you will receive a frame holding a tensioned stencil.

    * assembly requires additional steps, so there will be an additional guide written for this.

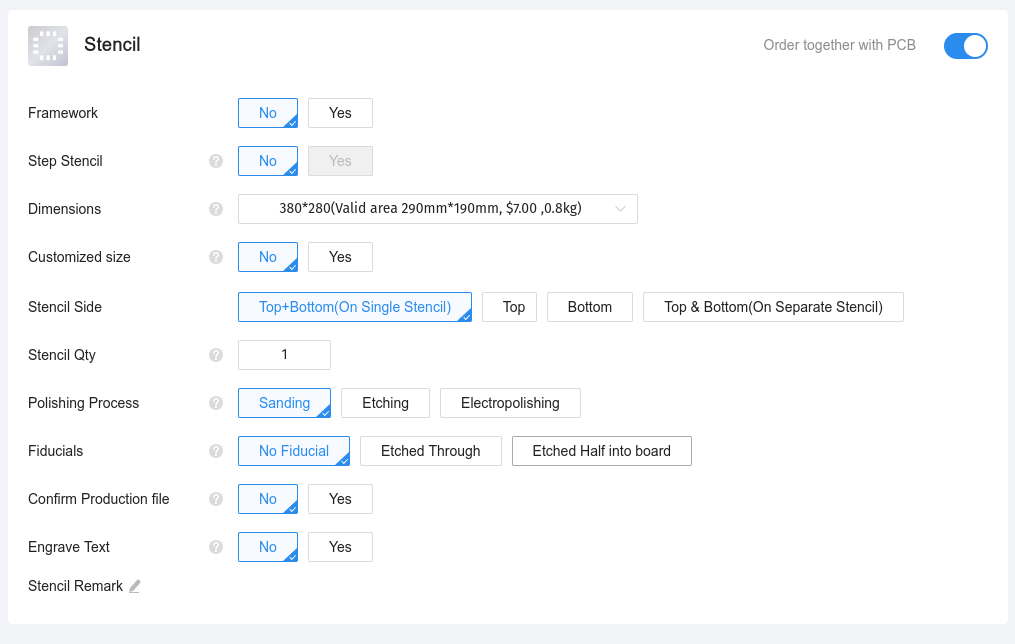
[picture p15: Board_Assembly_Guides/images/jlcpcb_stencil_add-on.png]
jlcpcb stencil options
    

    jlcpcb assembly options

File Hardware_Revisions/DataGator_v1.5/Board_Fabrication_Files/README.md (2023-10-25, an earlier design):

This directory contains the files supplied to PCBWay for ordering Data Gator v1.5 board fabrication and assembly service.

The file named `Aggregator Schematic v315_top_cpl.csv` contains the automation file for placing components on the top of the board.

`Aggregator Schematic v315_top_bom.csv` contains the preliminary bill of materials submitted to the company for the quotation. Note that after working with the engineers a corrected version was made. That is the third and final design file in this directory.

Using the gerber files in the directory above, you can order board fabrication. Submit the files in this directory to have components placed and soldered onto the board by PCBWay.

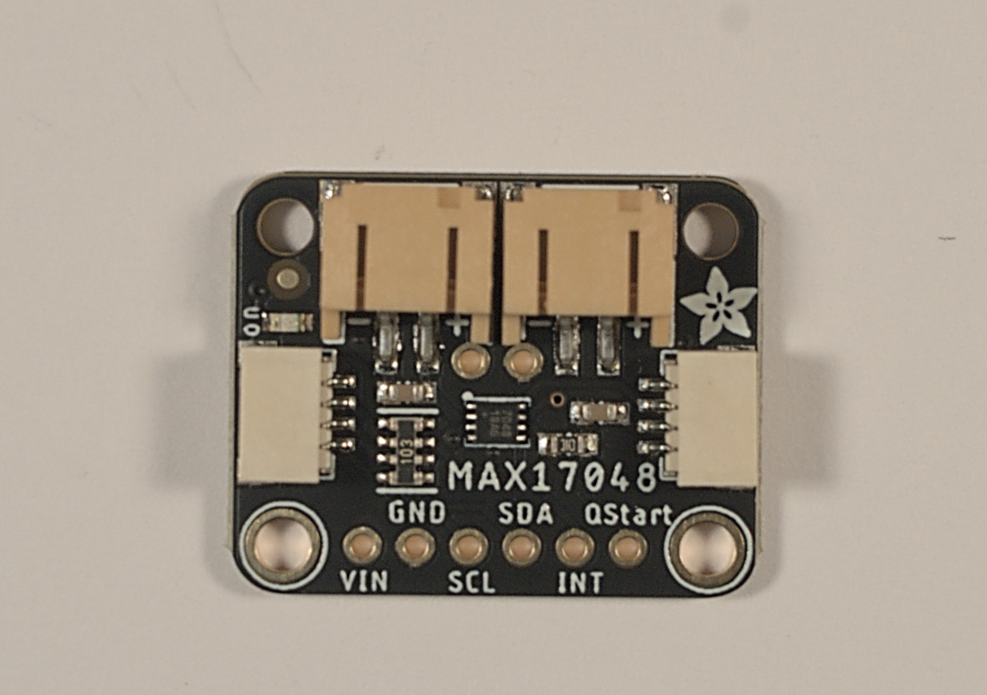
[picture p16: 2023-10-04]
Board_Assembly_Guides/images/fuel_gauge.jpg

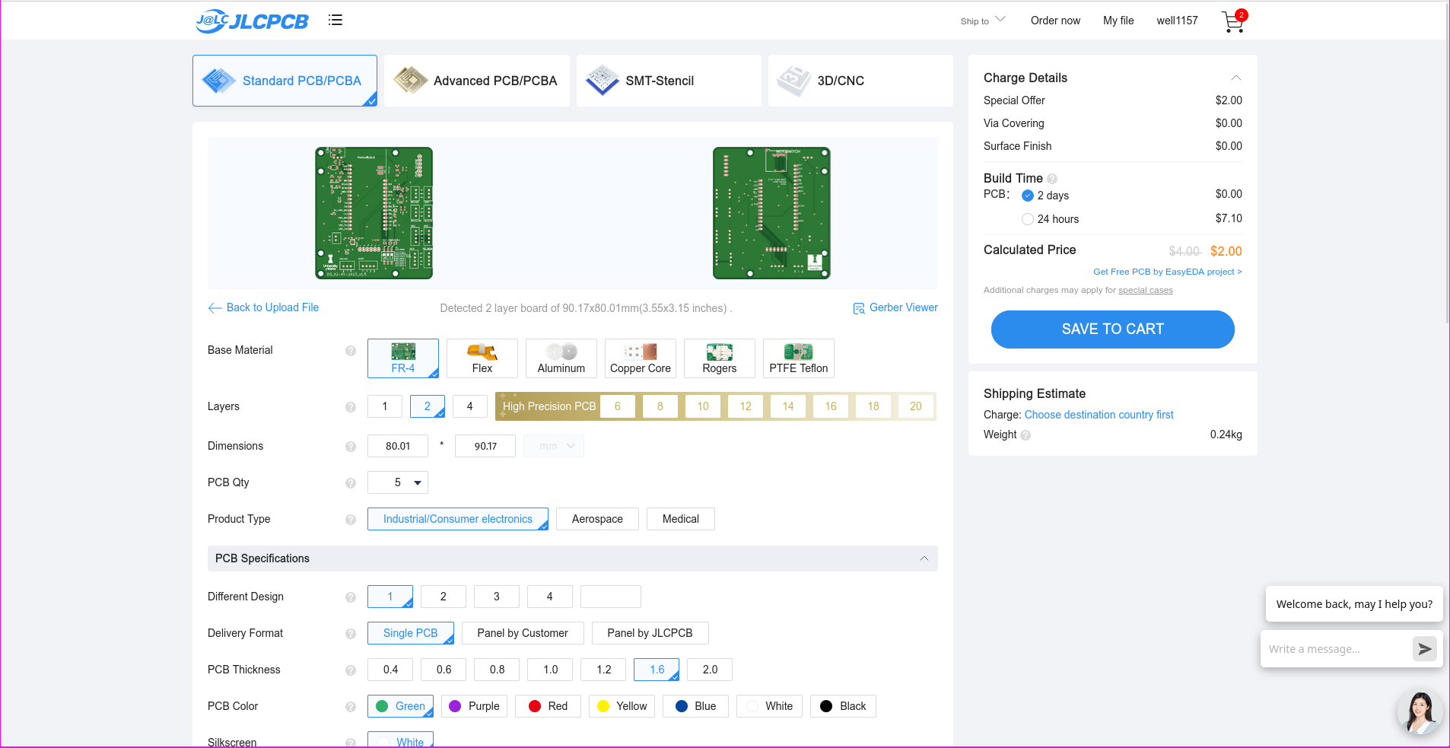
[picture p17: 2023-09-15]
Board_Assembly_Guides/images/jlcpcb_fabrication_options.png

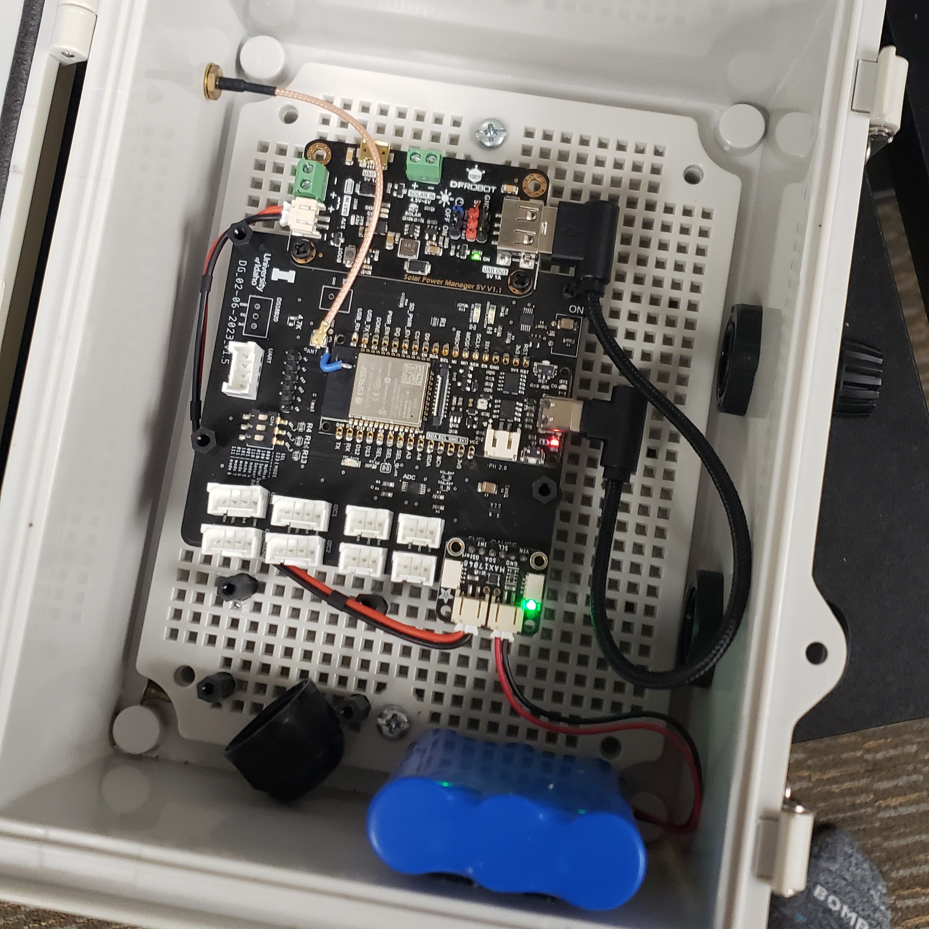
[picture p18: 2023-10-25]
Board_Assembly_Guides/images/enclosure/enclosure_topdown.jpg

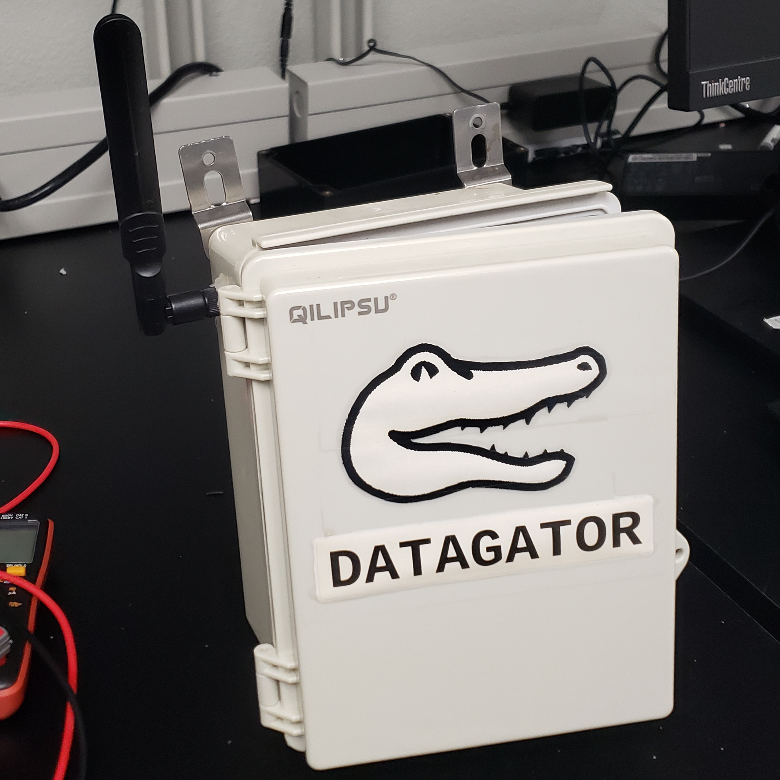
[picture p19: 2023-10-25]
Board_Assembly_Guides/images/enclosure/exterior_ortho.jpg

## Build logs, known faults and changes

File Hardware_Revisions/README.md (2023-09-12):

# Hardware Revisions

This directory contains documentation and design files for the Data Gator PCB designs.

In principle, each hardware revision directory will have the following:

1. Electrical schematic as a PDF,
2. Bill of Materials (BOM) as a spreadsheet,
3. 3D Model of the physical board and components for design of cases,
4. Assembly automation files for contracting assembly through 3rd party.

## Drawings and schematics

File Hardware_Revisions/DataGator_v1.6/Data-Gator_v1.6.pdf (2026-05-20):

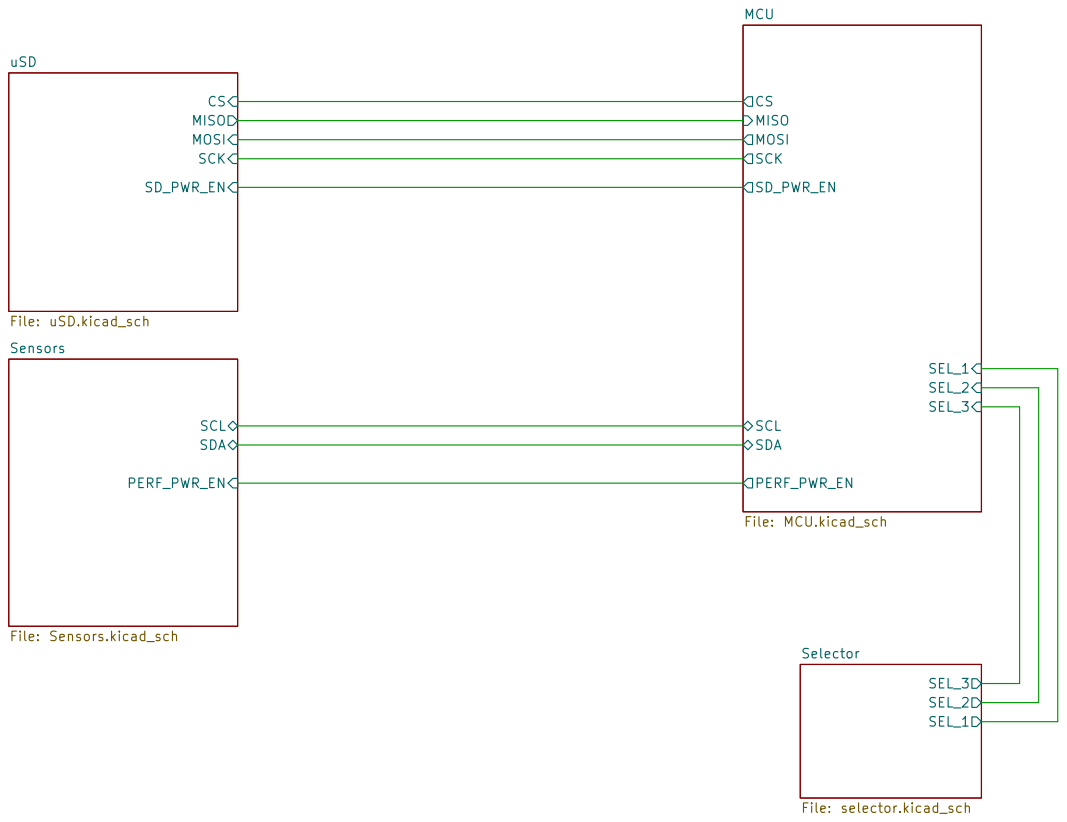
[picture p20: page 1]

SCL SDA CSMISO MOSI SCK MCU
Selector File: selector.kicad_sch SD_PWR_EN

File: MCU.kicad_sch SCL SDA PERF_PWR_EN

Authors: Garrett Wells, Kevin Wing
University of Idaho
Sheet: /
File: Data-Gator_v1.6.kicad_sch
Title: Data Gator

Size: USLetter | Rev: 1.6
KiCad E.D.A. 10.0.3 | Id: 1/7

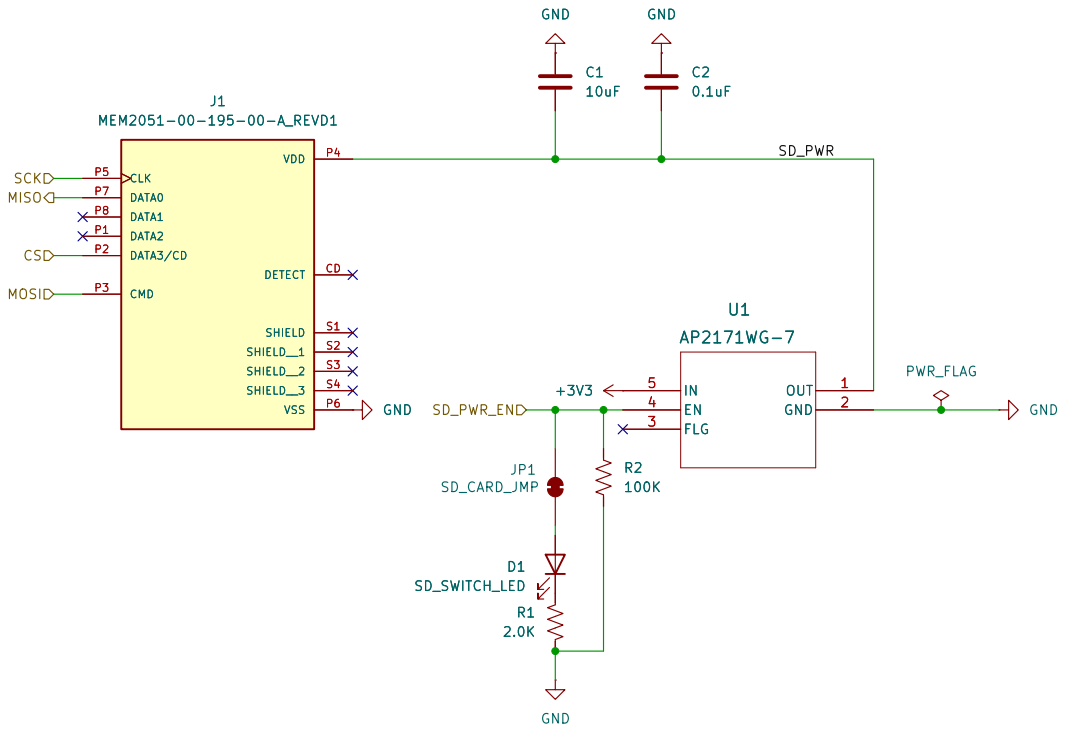
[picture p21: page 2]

Authors: Garrett Wells, Kevin Wing
University of Idaho
Sheet: /uSD/
File: uSD.kicad_sch
Title: Data Gator

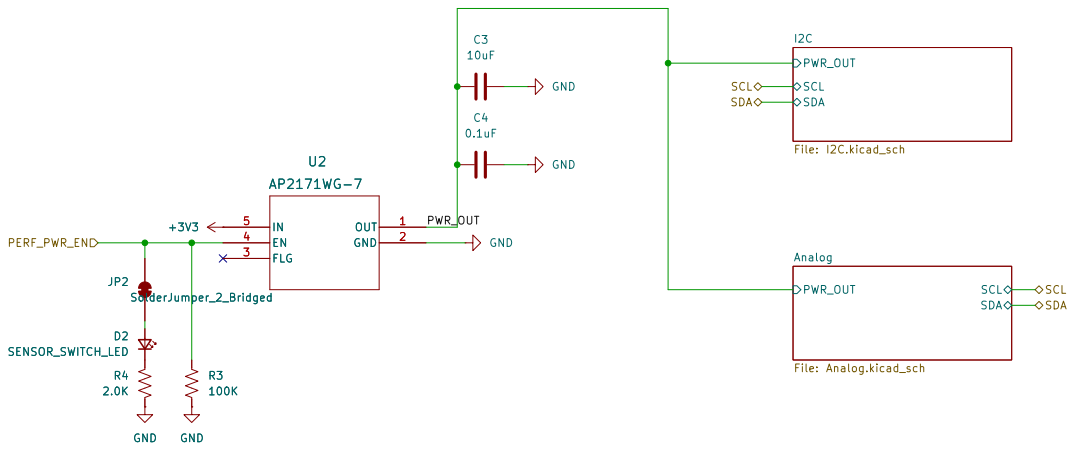
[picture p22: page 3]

Authors: Garrett Wells, Kevin Wing
University of Idaho
Sheet: /Sensors/
File: Sensors.kicad_sch
Title: Data Gator

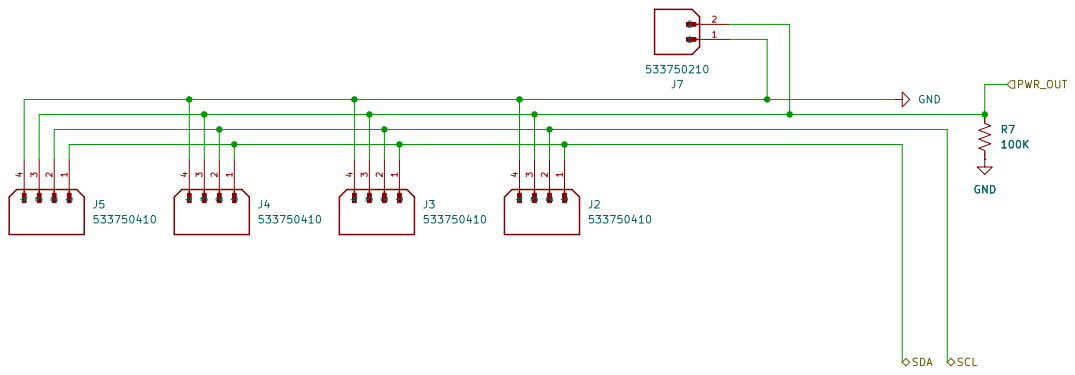
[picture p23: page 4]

Authors: Garrett Wells, Kevin Wing
University of Idaho
Sheet: /Sensors/I2C/
File: I2C.kicad_sch
Title: Data Gator

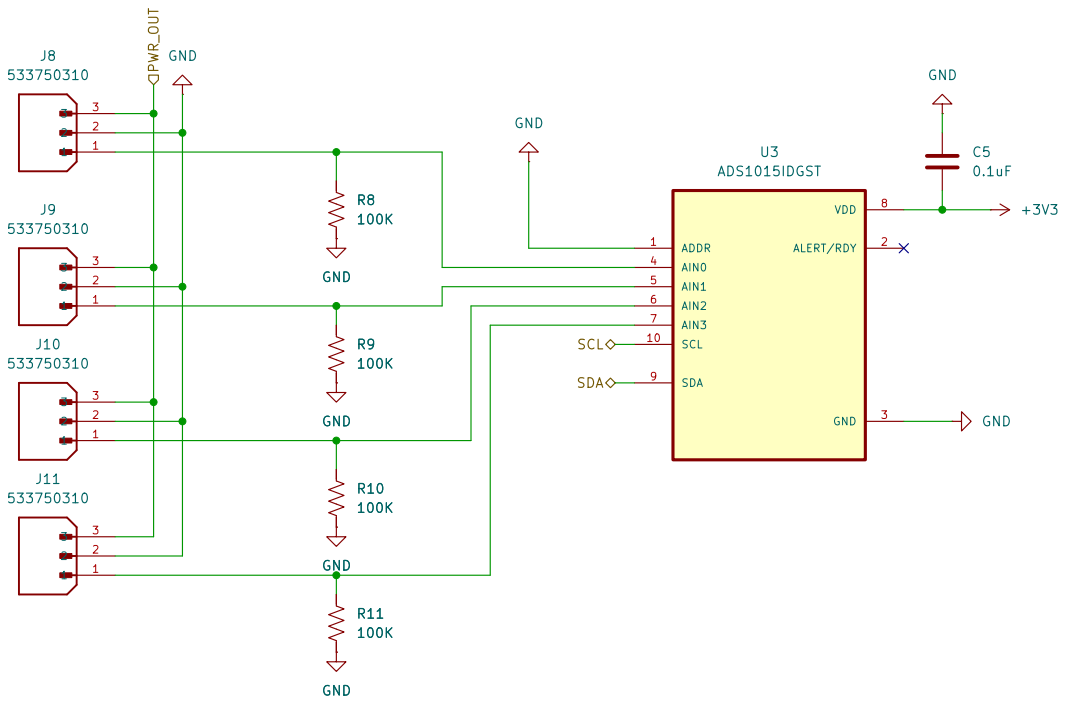
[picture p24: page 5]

Authors: Garrett Wells, Kevin Wing
University of Idaho
Sheet: /Sensors/Analog/
File: Analog.kicad_sch
Title: Data Gator

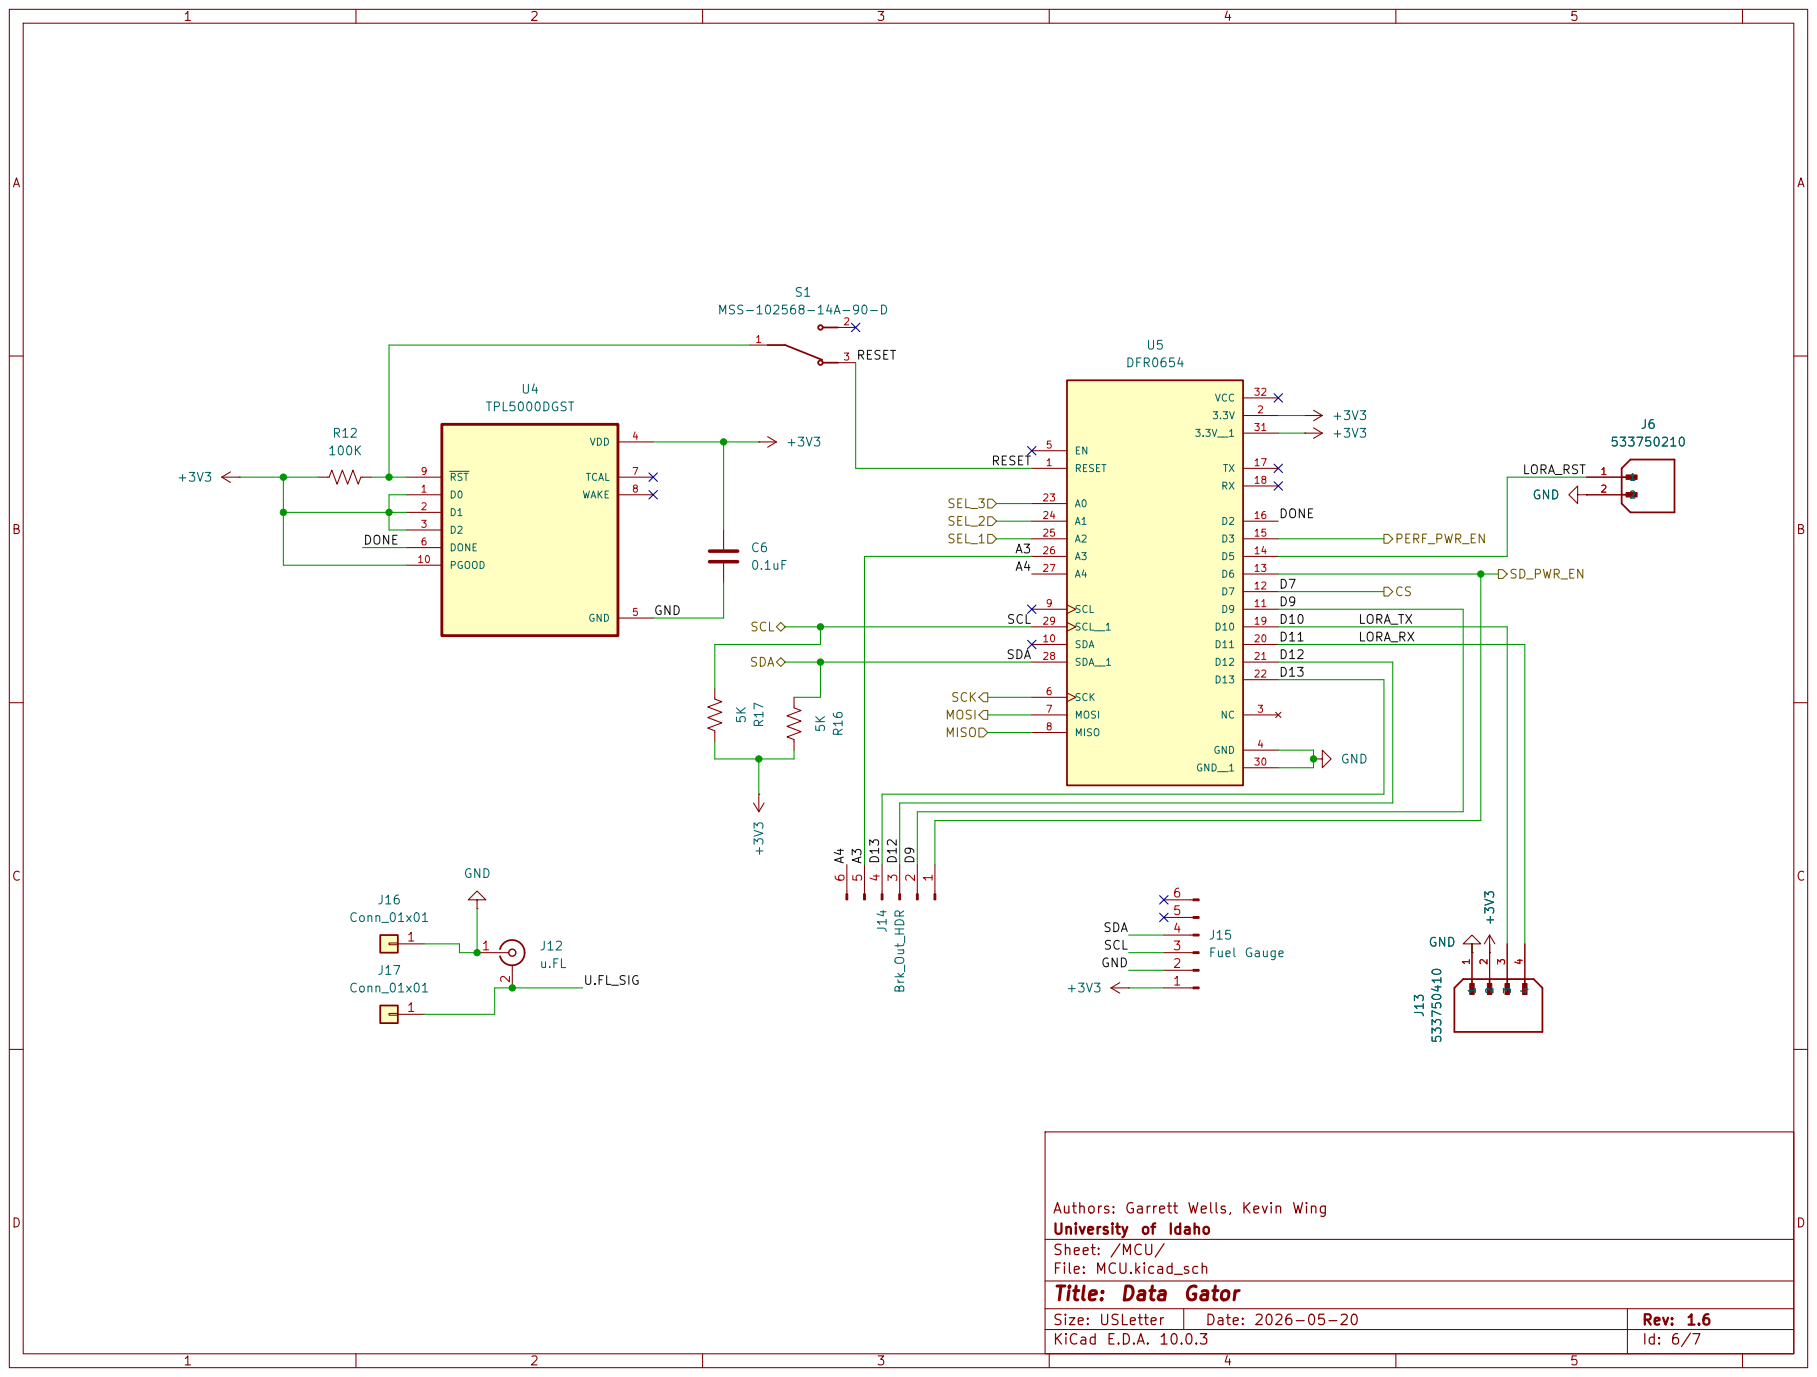
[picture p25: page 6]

Authors: Garrett Wells, Kevin Wing
University of Idaho
Sheet: /MCU/
File: MCU.kicad_sch
Title: Data Gator

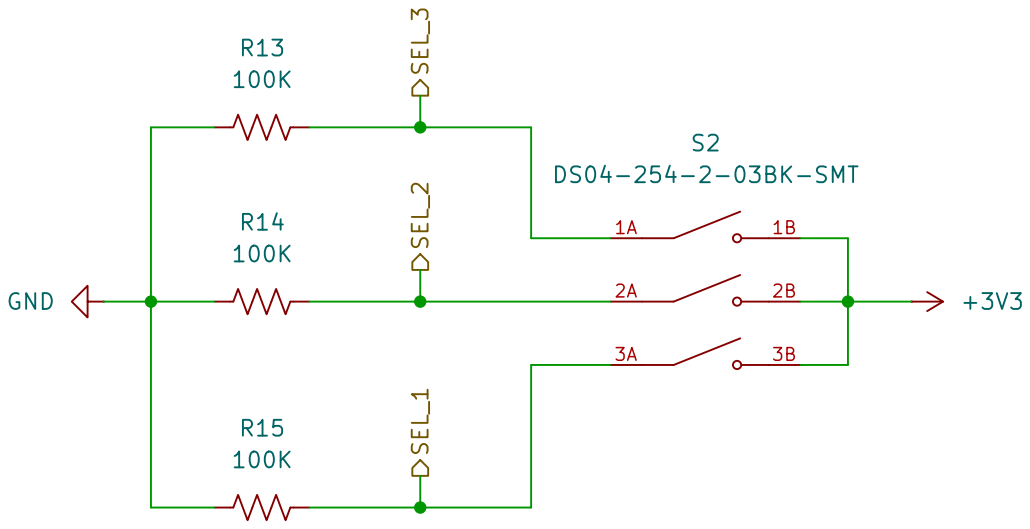
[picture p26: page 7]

Authors: Garrett Wells, Kevin Wing
University of Idaho
Sheet: /Selector/
File: selector.kicad_sch
Title: Data Gator

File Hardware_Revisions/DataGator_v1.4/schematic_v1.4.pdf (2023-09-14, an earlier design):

# WDT_SWITCH

2

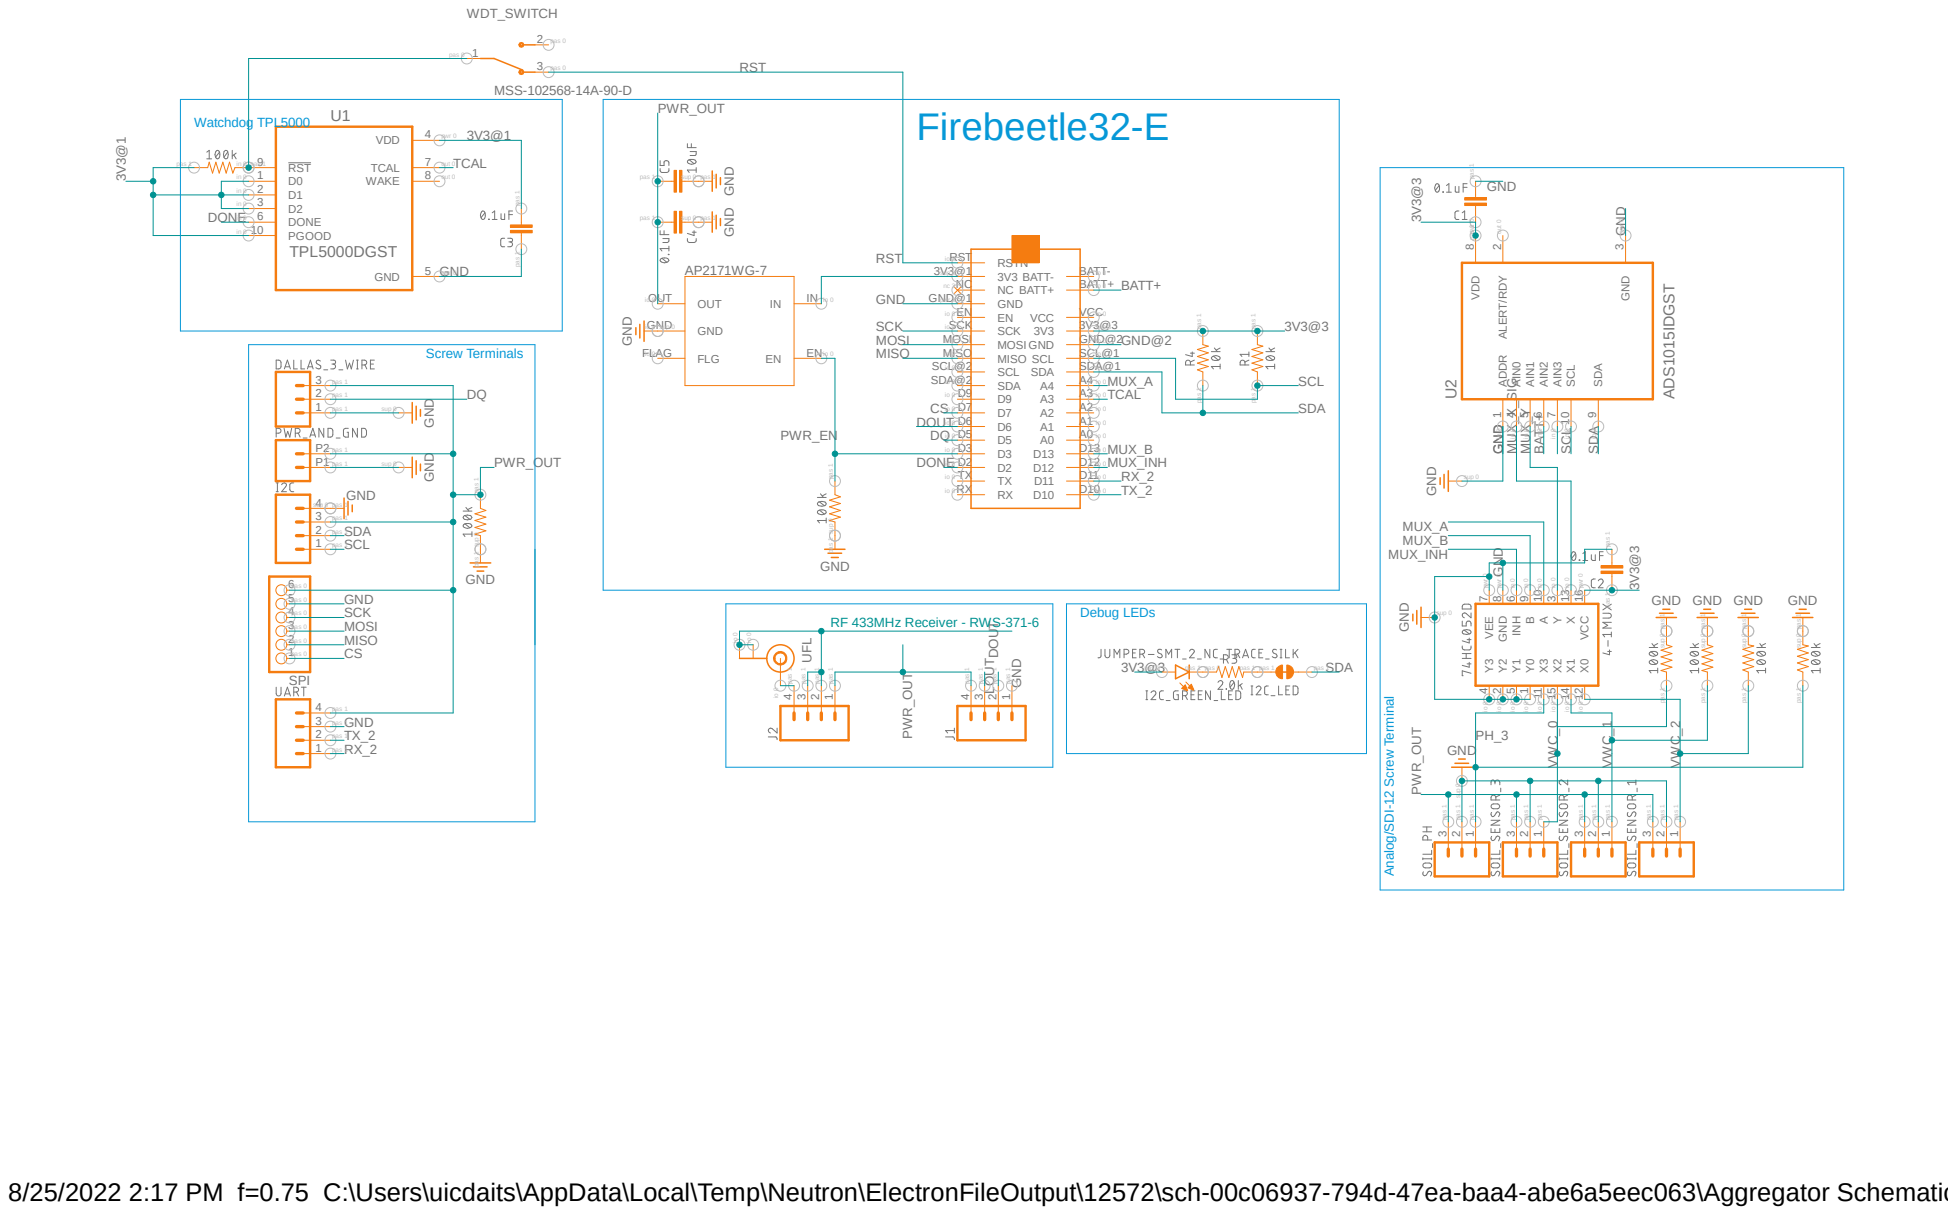
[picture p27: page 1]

8/25/2022 2:17 PM f=0.75 C:\Users\uicdaits\AppData\Local\Temp\Neutron\ElectronFileOutput\12572\sch-00c06937-794d-47ea-baa4-abe6a5eec063\Aggregator Schematic v104.sch (Sheet: 1/2)

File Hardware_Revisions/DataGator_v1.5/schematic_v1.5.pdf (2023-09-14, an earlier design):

BATT- | BATT- BATT+ | BATT+ WDT_SWITCH

3

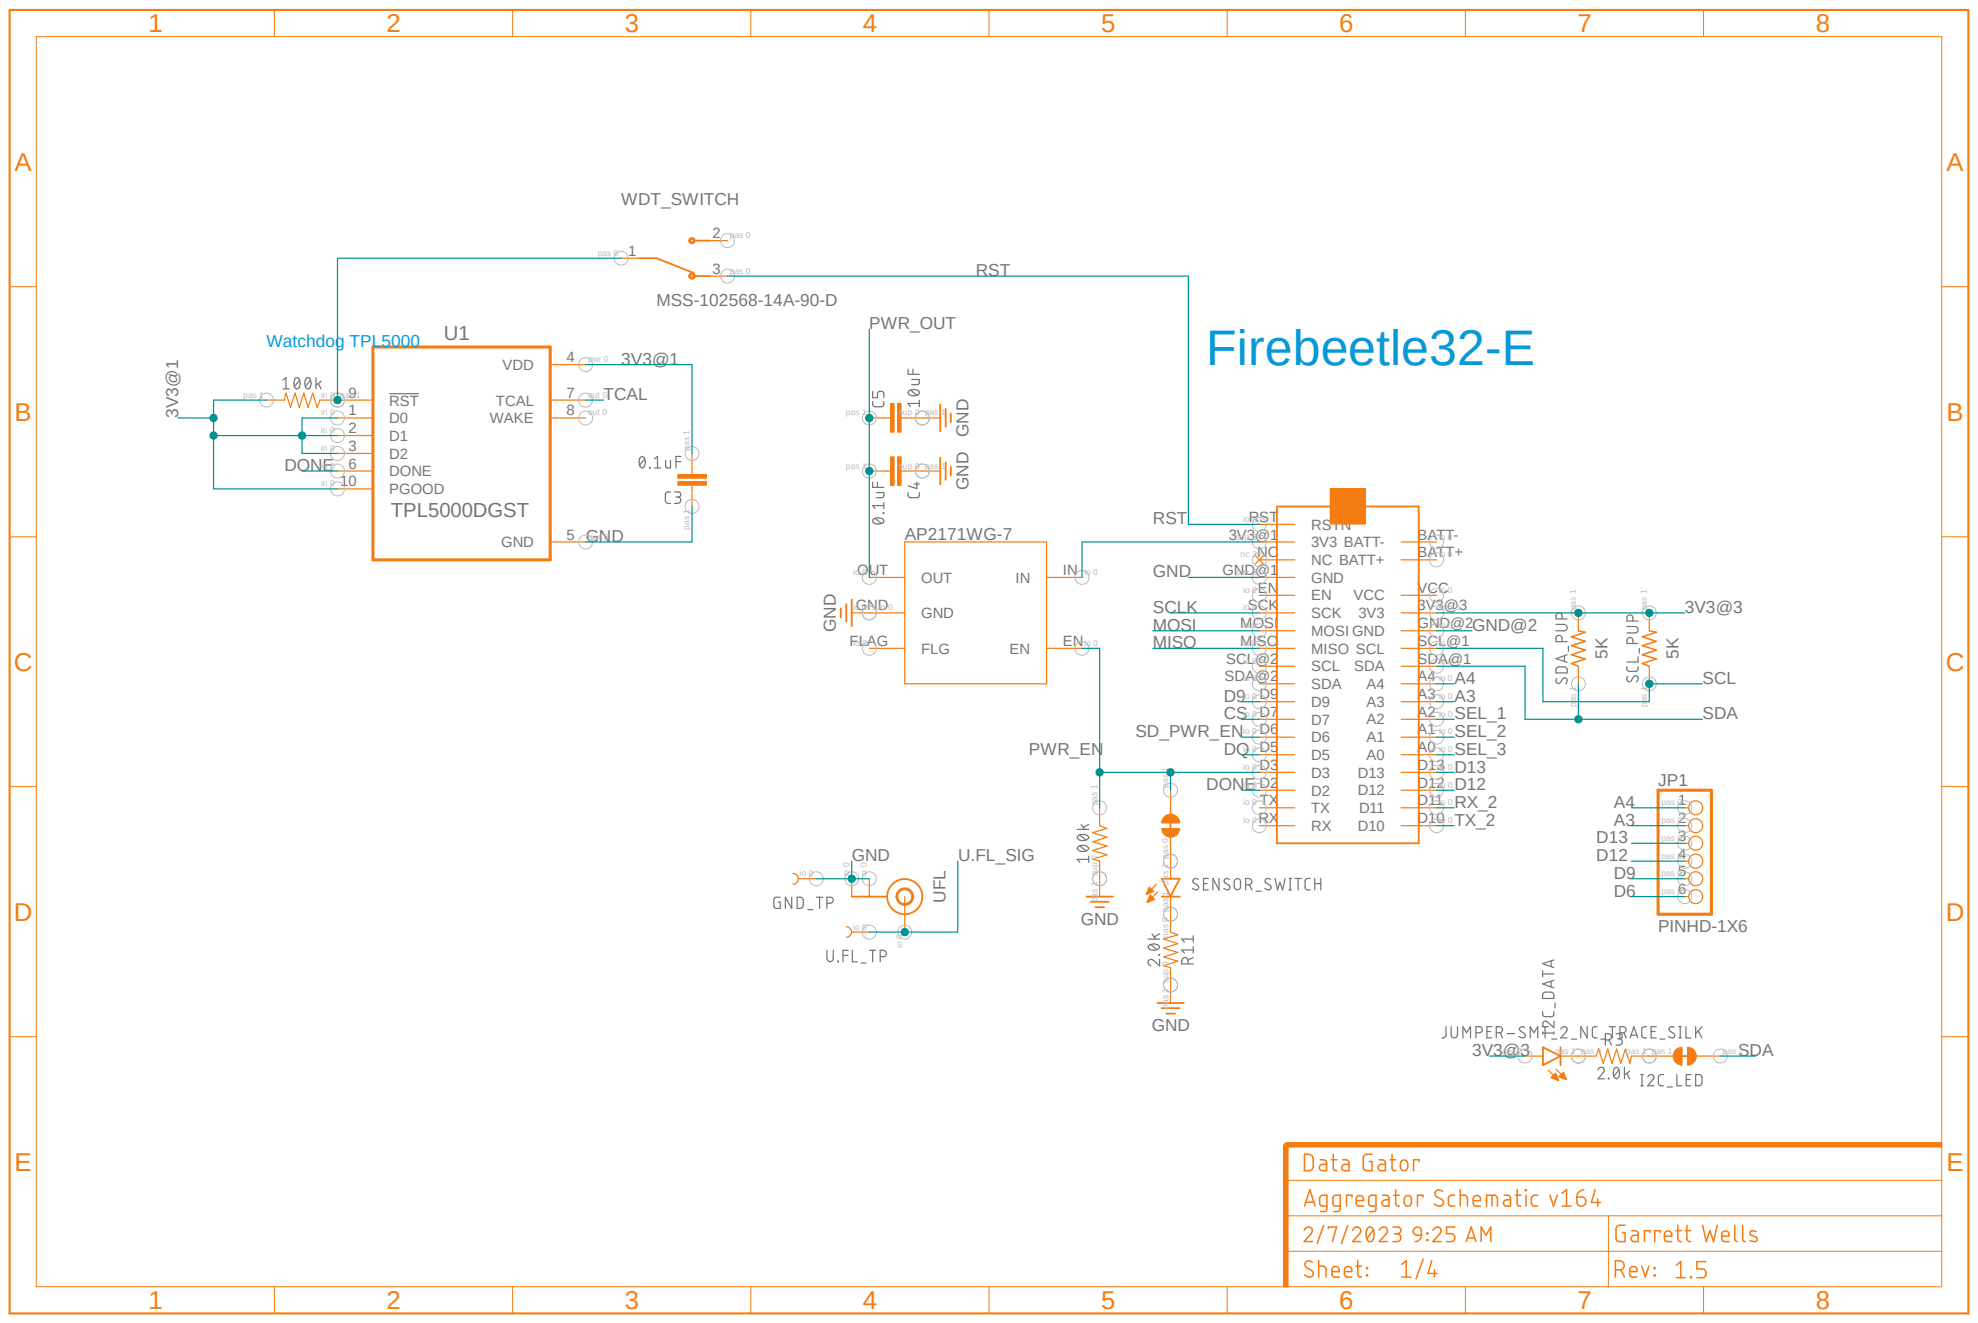
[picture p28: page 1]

A

A

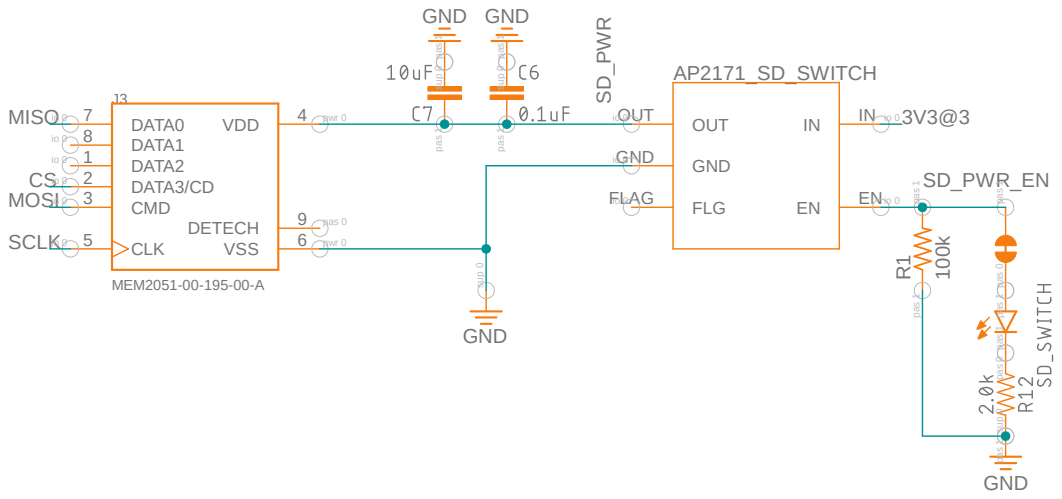
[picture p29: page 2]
MEM2051-00-195-00-A; GND; GND GND; GND ¹⁰⁰k; J3 DATA2 1; DATA3/CD 2; CMD 3; VDD; 4 CLK 5; VSS; 6 DATA0 7; DATA1 8; DETECH; AP2171_SD_SWITCH OUT OUT; FLG FLAG; MOSI; MISO; SCLK; SD_PWR_EN SD_PWR; pwr 0; pas 0; io 0 sup 0; pas 1 pas 1; pas 1 pas 1 sup 0; sup 0; pas 0 pas 0 sup 0 pas 1 pas 1 pas 1 pas 1

A

A

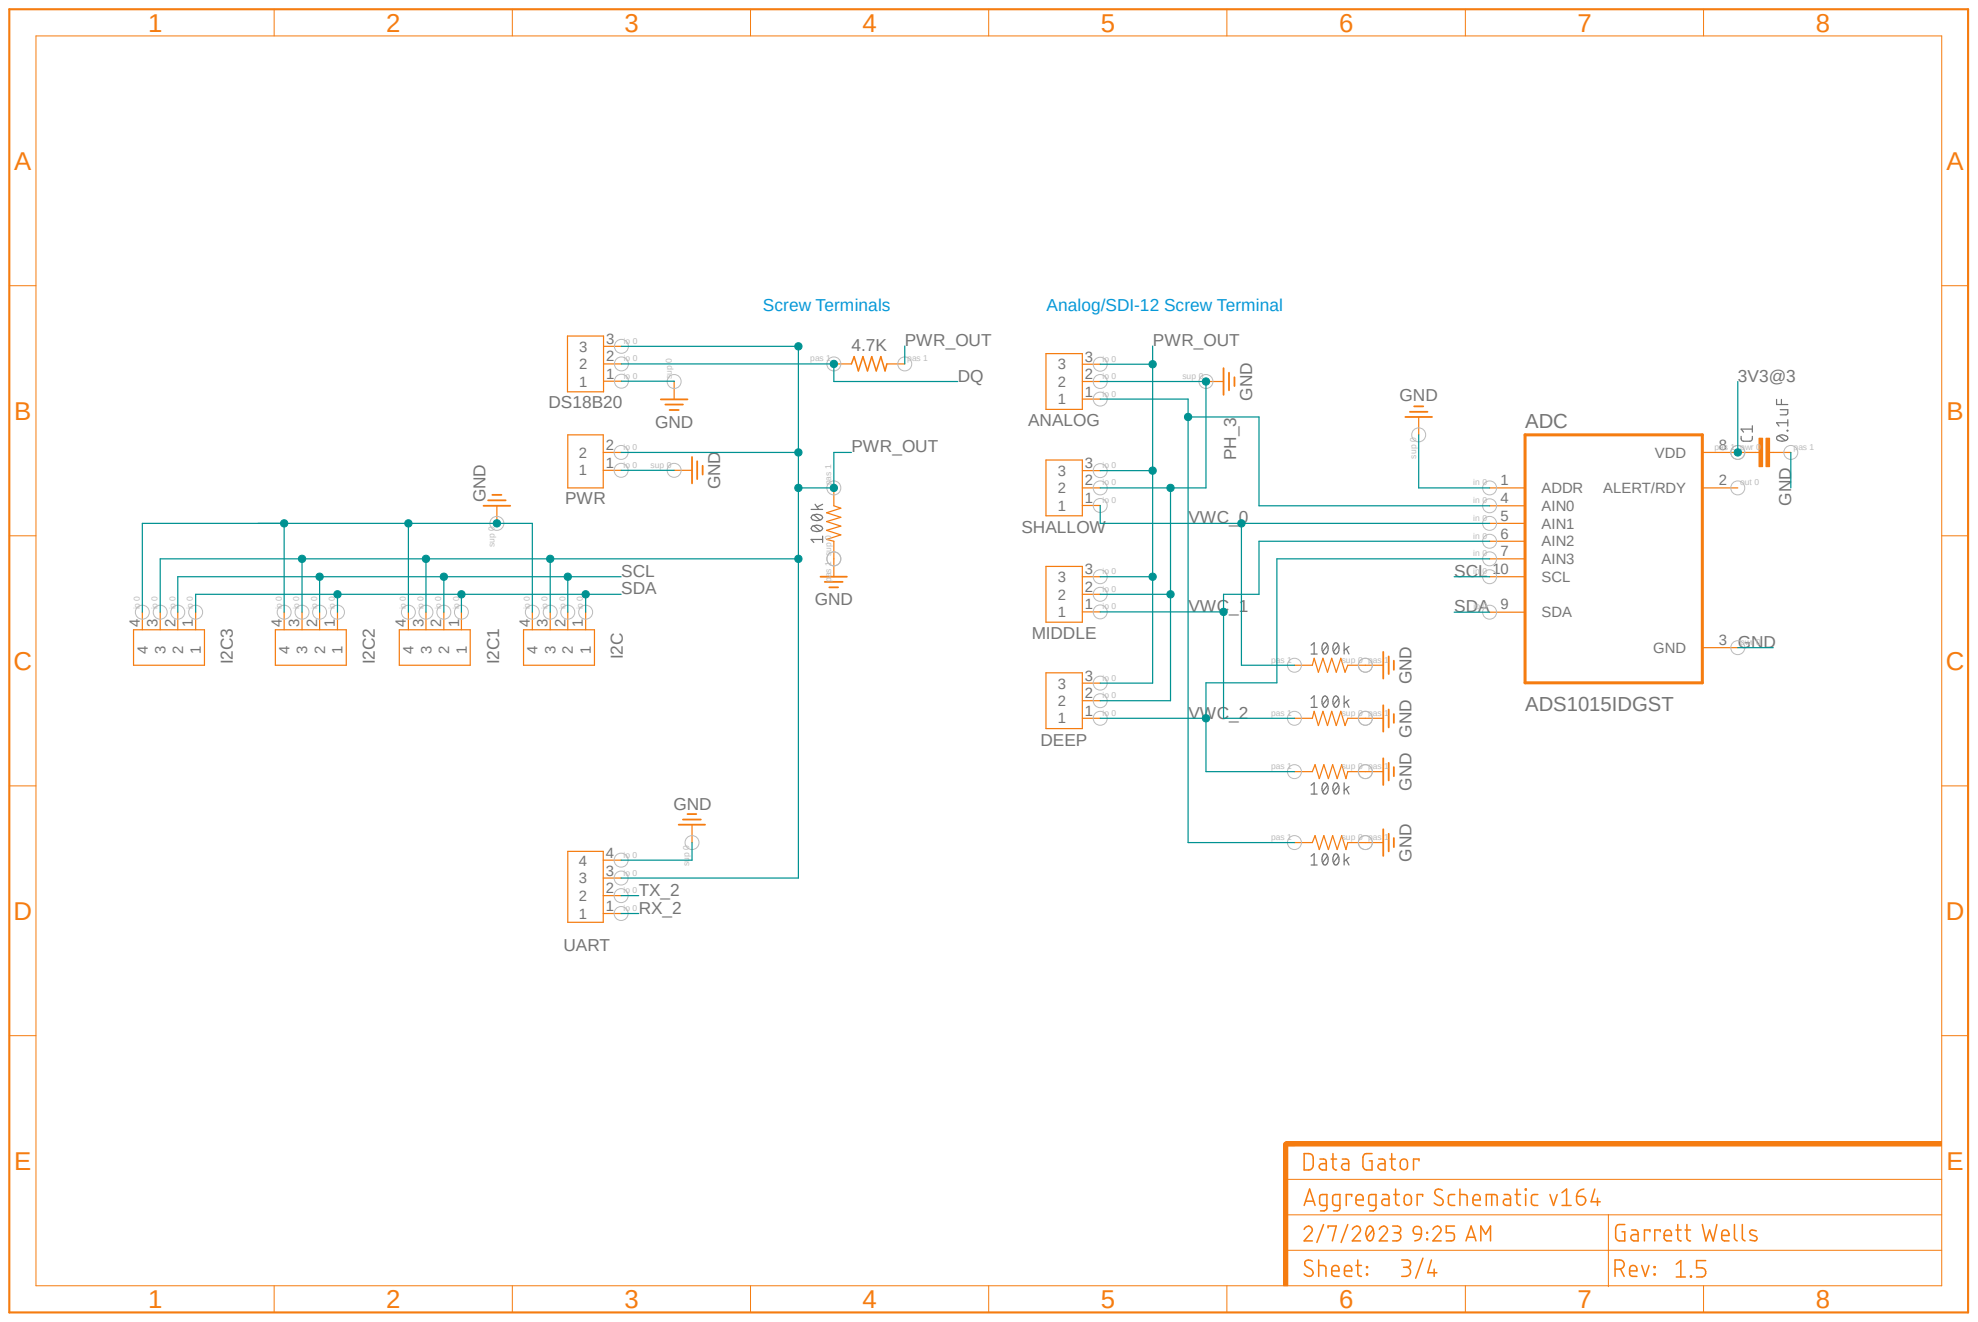
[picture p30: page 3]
GNDGND; GND; ADC; ADDR 1; AIN0 4; AIN1 5; AIN2 6; AIN3 7; SCL 10; SDA 9; VDD; 8 ALERT/RDY; 2 GND; 3 ANALOG; 3 SHALLOW; 3 MIDDLE; 3 DEEP; 4 UART; PWR; 4 GND; SCL; SDA; PWR_OUT; VWC_2PH_3; VWC_0; VWC_1; 8 sup 0; sup 0sup 0; pas 1 pas 1 sup 0; pas 1; sup 0; pwr 0; out 0; sup 0 pas 1; Screw Terminals; Analog/SDI-12 Screw Terminal

ADS1015IDGST GND GND GND GND

SDA | ON | 1 2 3 ABCDE | 1 | 2 | 3 | 4 | 5 | 6 | 7 | 8 | ABCDE 1 | 2 | 3 | 4 | 5 | 6 | 7 | 8

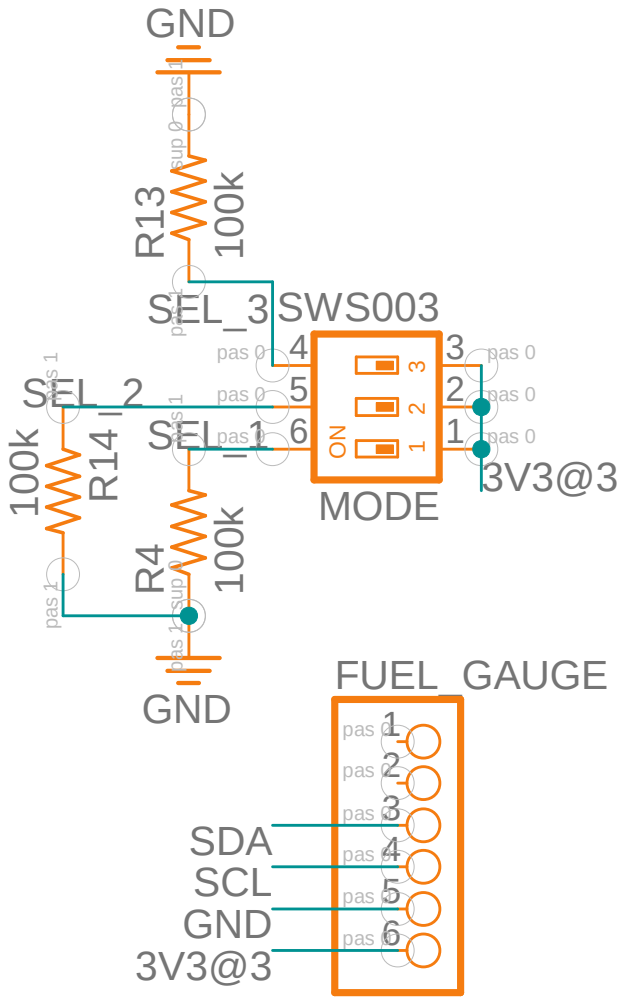
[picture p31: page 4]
GND; MODE ⁴⁵; SEL_3; SEL_2; SEL_1; SCL; pas 0; pas 0 pas 1 pas 1 pas 1 pas 1 pas 1 pas 1; sup 0 sup 0

SWS003 100k 100k 100k
6 123 FUEL_GAUGE 123456 R⁴ R¹³ R¹⁴

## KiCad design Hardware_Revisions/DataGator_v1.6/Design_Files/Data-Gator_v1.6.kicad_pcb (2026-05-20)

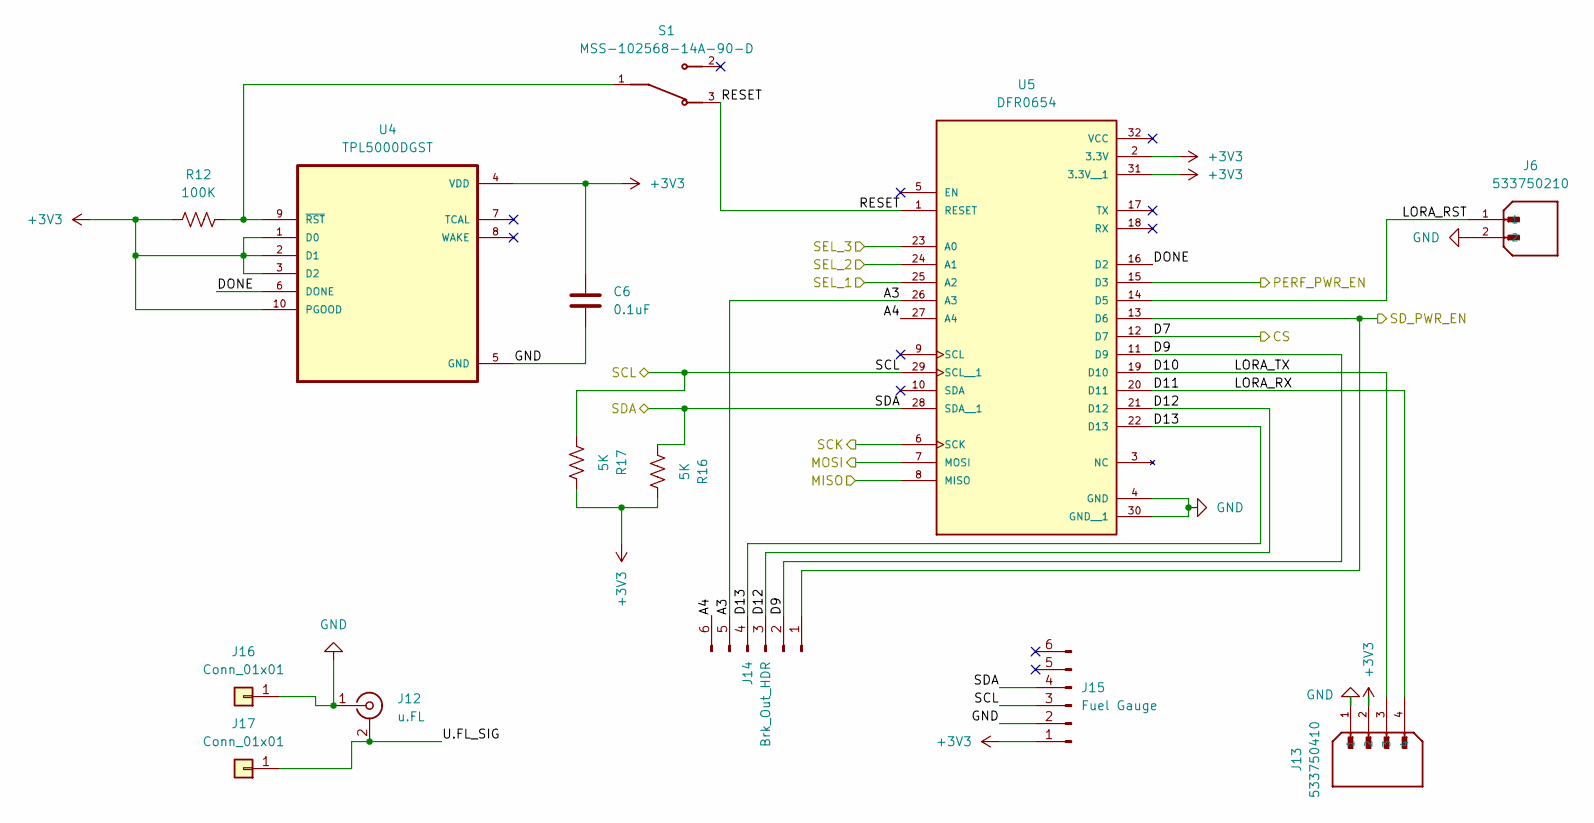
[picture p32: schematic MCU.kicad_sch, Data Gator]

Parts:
C6: 0.1uF; C_0603_1608Metric
J6: 533750210; MOLEX_533750210; PARTREV C
J12: u.FL; U.FL_Hirose_U.FL-R-SMT-1_Vertical
J13: 533750410; MOLEX_533750410; PARTREV C
J14: Brk_Out_HDR; PinHeader_1x06_P2.54mm_Vertical
J15: Fuel Gauge; PinHeader_1x06_P2.54mm_Vertical
J16, J17: Conn_01x01; SolderWirePad_1x01_SMD_1x2mm
R12: 100K; R_0603_1608Metric
R16, R17: 5K; R_0603_1608Metric
S1: MSS-102568-14A-90-D; SW_MSS-102568-14A-90-D; PARTREV 1.0
U4: TPL5000DGST; SOP50P490X110-10N
U5: DFR0654; MODULE_DFR0654

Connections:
+3V3: C6.1, J13.2, J15.1, R12.1, R16.2, R17.2, U4.1 (D0), U4.2 (D1), U4.3 (D2), U4.4 (VDD), U4.10 (PGOOD), U5.2 (3.3V), U5.31 (3.3V__1); also elsewhere on the board
/MCU/A3: J14.5, U5.26 (A3)
/MCU/A4: J14.6, U5.27 (A4)
/MCU/D7: U5.12 (D7); also elsewhere on the board
/MCU/D9: J14.2, U5.11 (D9)
/MCU/D10: J13.3, U5.19 (D10)
/MCU/D11: J13.4, U5.20 (D11)
/MCU/D12: J14.3, U5.21 (D12)
/MCU/D13: J14.4, U5.22 (D13)
/MCU/DONE: U4.6 (DONE), U5.16 (D2)
/MCU/LORA_RST: J6.1, U5.14 (D5)
/MCU/MISO: U5.8 (MISO); also elsewhere on the board
/MCU/MOSI: U5.7 (MOSI); also elsewhere on the board
/MCU/PERF_PWR_EN: U5.15 (D3); also elsewhere on the board
/MCU/RESET: S1.3, U5.1 (RESET)
/MCU/SCK: U5.6 (SCK); also elsewhere on the board
/MCU/SCL: J15.3, R17.1, U5.29 (SCL__1); also elsewhere on the board
/MCU/SDA: J15.4, R16.1, U5.28 (SDA__1); also elsewhere on the board
/MCU/SD_PWR_EN: J14.1, U5.13 (D6); also elsewhere on the board
/MCU/SEL_1: U5.25 (A2); also elsewhere on the board
/MCU/SEL_2: U5.24 (A1); also elsewhere on the board
/MCU/SEL_3: U5.23 (A0); also elsewhere on the board
/MCU/U.FL_SIG: J12.2 (Ext), J17.1 (Pin_1_1)
GND: C6.2, J6.2, J12.1 (In), J13.1, J15.2, J16.1 (Pin_1_1), U4.5 (GND), U5.4 (GND), U5.30 (GND__1); also elsewhere on the board
unnamed: R12.2, S1.1, U4.9 (~RST)

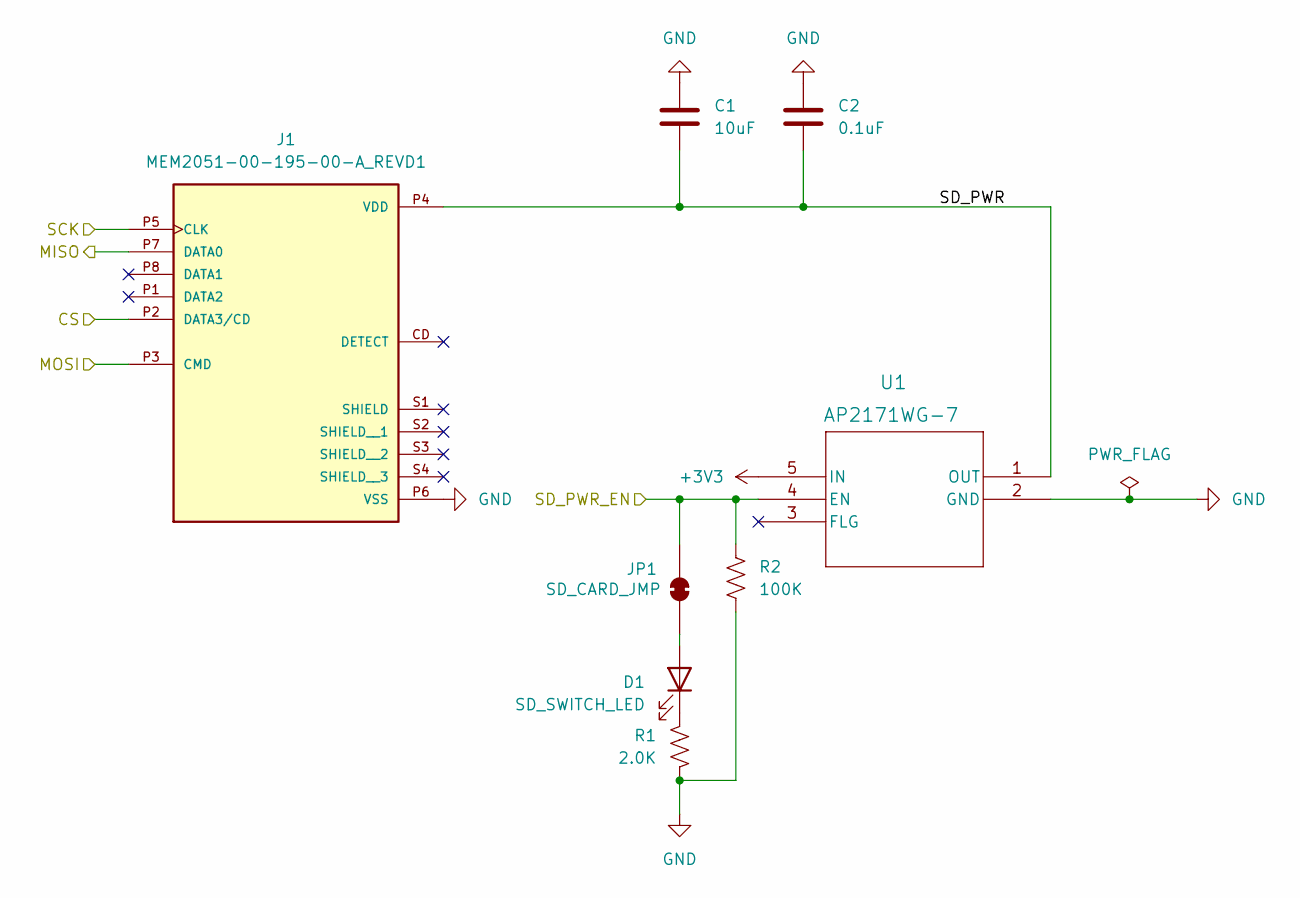
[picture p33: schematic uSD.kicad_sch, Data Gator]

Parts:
C1: 10uF; C_1210_3225Metric
C2: 0.1uF; C_0603_1608Metric
D1: SD_SWITCH_LED; LED_1206_3216Metric
J1: MEM2051-00-195-00-A_REVD1; GCT_MEM2051-00-195-00-A_REVD1; PARTREV D1
JP1: SD_CARD_JMP; SolderJumper-2_P1.3mm_Bridged_Pad1.0x1.5mm
R1: 2.0K; R_0603_1608Metric
R2: 100K; R_0603_1608Metric
U1: AP2171WG-7; SOT25_DIO

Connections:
+3V3: U1.5 (IN); also elsewhere on the board
/MCU/D7: J1.P2 (DATA3/CD); also elsewhere on the board
/MCU/MISO: J1.P7 (DATA0); also elsewhere on the board
/MCU/MOSI: J1.P3 (CMD); also elsewhere on the board
/MCU/SCK: J1.P5 (CLK); also elsewhere on the board
/MCU/SD_PWR_EN: JP1.1 (A), R2.1, U1.4 (EN); also elsewhere on the board
/uSD/SD_PWR: C1.2, C2.2, J1.P4 (VDD), U1.1 (OUT)
GND: C1.1, C2.1, J1.P6 (VSS), R1.2, R2.2, U1.2 (GND); also elsewhere on the board
unnamed: D1.2 (A), JP1.2 (B)
unnamed: D1.1 (K), R1.1

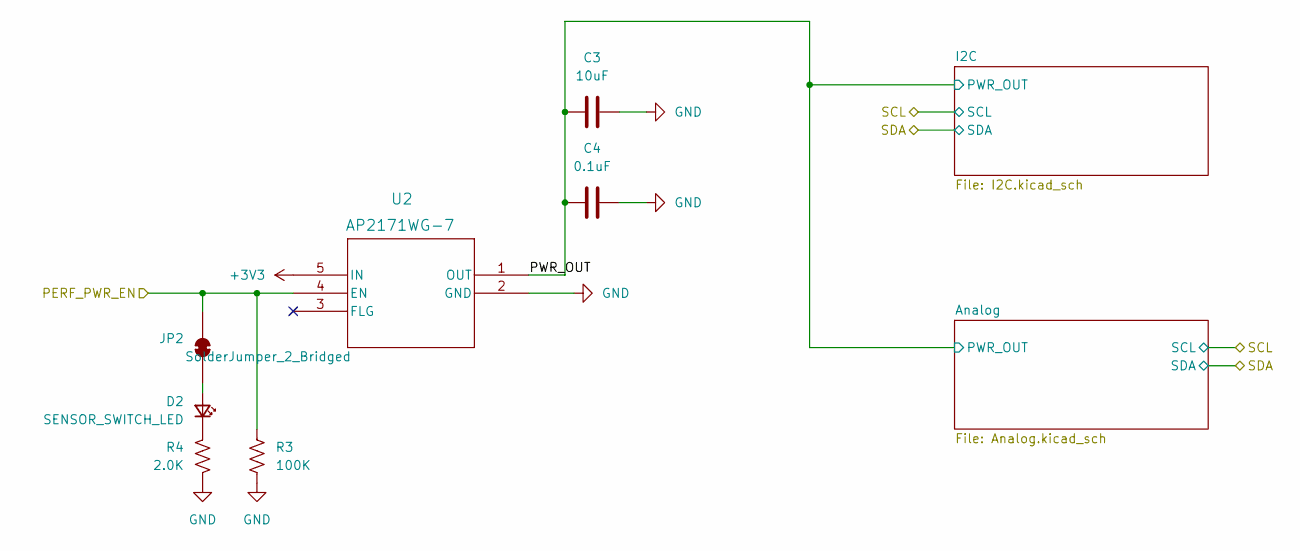
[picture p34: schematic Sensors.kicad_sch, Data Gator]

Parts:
C3: 10uF; C_1210_3225Metric
C4: 0.1uF; C_0603_1608Metric
D2: SENSOR_SWITCH_LED; LED_1206_3216Metric
JP2: SolderJumper_2_Bridged; SolderJumper-2_P1.3mm_Bridged_Pad1.0x1.5mm
R3: 100K; R_0603_1608Metric
R4: 2.0K; R_0603_1608Metric
U2: AP2171WG-7; SOT25_DIO

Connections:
+3V3: U2.5 (IN); also elsewhere on the board
/MCU/PERF_PWR_EN: JP2.2 (B), R3.2, U2.4 (EN); also elsewhere on the board
/Sensors/PWR_OUT: C3.1, C4.1, U2.1 (OUT); also elsewhere on the board
GND: C3.2, C4.2, R3.1, R4.2, U2.2 (GND); also elsewhere on the board
unnamed: D2.2 (A), JP2.1 (A)
unnamed: D2.1 (K), R4.1

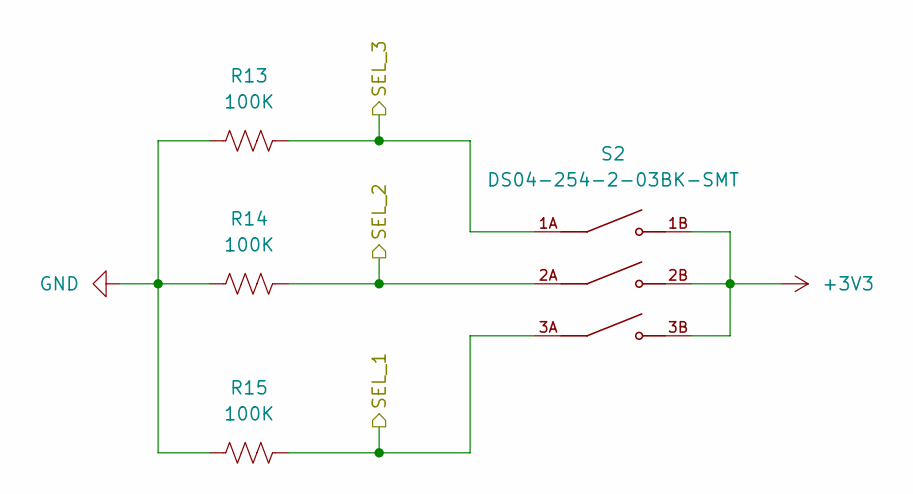
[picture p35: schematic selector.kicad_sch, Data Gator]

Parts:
R13, R14, R15: 100K; R_0603_1608Metric
S2: DS04-254-2-03BK-SMT; SW_DS04-254-2-03BK-SMT; PARTREV V0.0

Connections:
+3V3: S2.1B, S2.2B, S2.3B; also elsewhere on the board
/MCU/SEL_1: R15.2, S2.3A; also elsewhere on the board
/MCU/SEL_2: R14.2, S2.2A; also elsewhere on the board
/MCU/SEL_3: R13.2, S2.1A; also elsewhere on the board
GND: R13.1, R14.1, R15.1; also elsewhere on the board

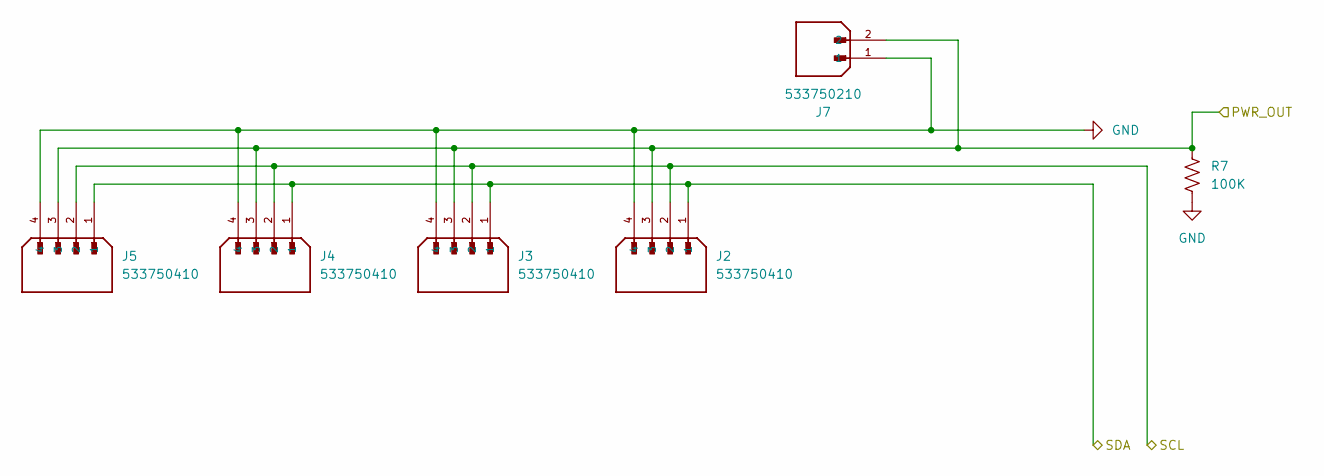
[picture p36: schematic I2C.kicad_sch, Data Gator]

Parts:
J2, J3, J4, J5: 533750410; MOLEX_533750410; PARTREV C
J7: 533750210; MOLEX_533750210; PARTREV C
R7: 100K; R_0603_1608Metric

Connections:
/MCU/SCL: J2.2, J3.2, J4.2, J5.2; also elsewhere on the board
/MCU/SDA: J2.1, J3.1, J4.1, J5.1; also elsewhere on the board
/Sensors/PWR_OUT: J2.3, J3.3, J4.3, J5.3, J7.2, R7.1; also elsewhere on the board
GND: J2.4, J3.4, J4.4, J5.4, J7.1, R7.2; also elsewhere on the board

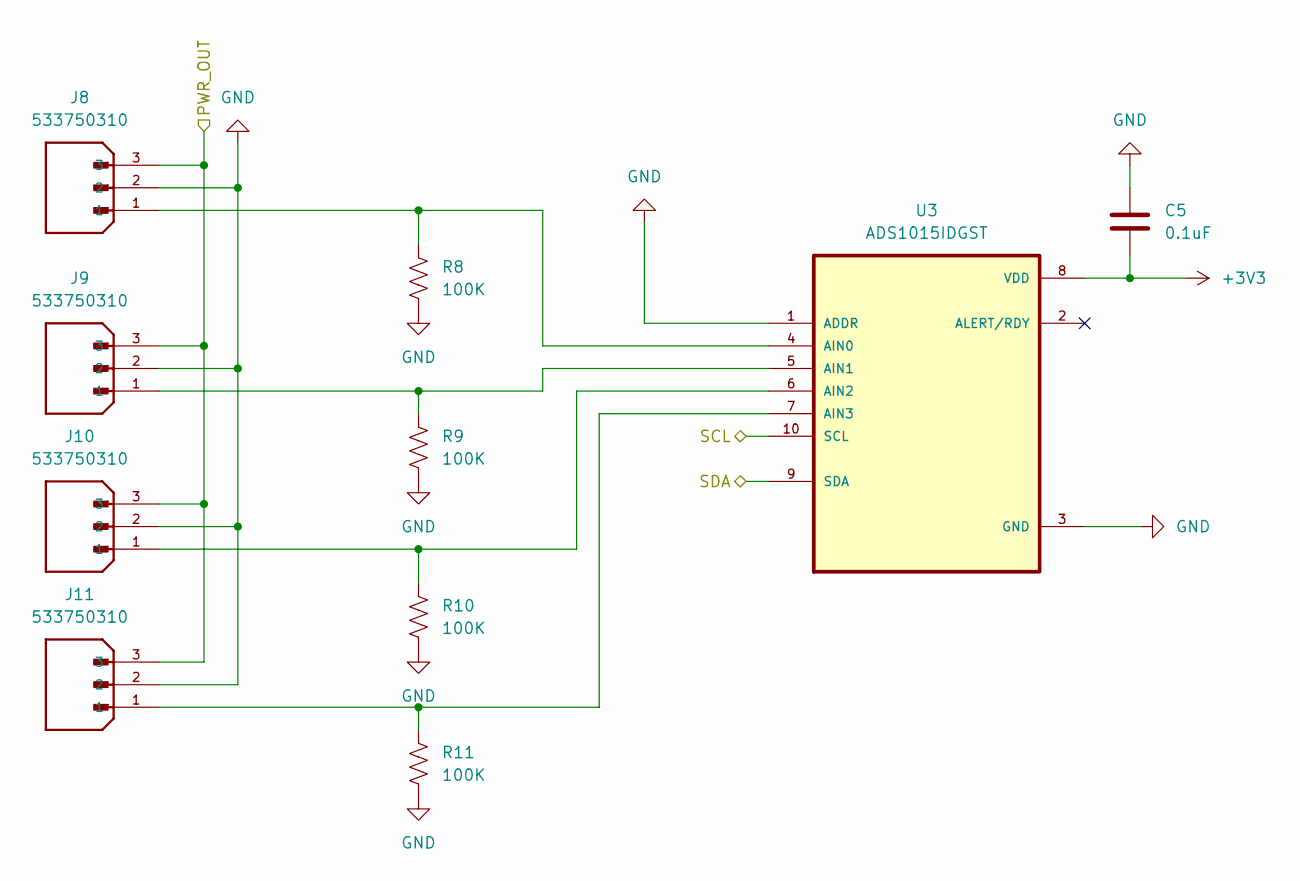
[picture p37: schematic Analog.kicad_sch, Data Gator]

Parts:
C5: 0.1uF; C_0603_1608Metric
J8, J9, J10, J11: 533750310; MOLEX_533750310; PARTREV C
R8, R9, R10, R11: 100K; R_0603_1608Metric
U3: ADS1015IDGST; SOP50P490X110-10N

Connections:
+3V3: C5.2, U3.8 (VDD); also elsewhere on the board
/MCU/SCL: U3.10 (SCL); also elsewhere on the board
/MCU/SDA: U3.9 (SDA); also elsewhere on the board
/Sensors/PWR_OUT: J8.3, J9.3, J10.3, J11.3; also elsewhere on the board
GND: C5.1, J8.2, J9.2, J10.2, J11.2, R8.2, R9.2, R10.2, R11.2, U3.1 (ADDR), U3.3 (GND); also elsewhere on the board
unnamed: J8.1, R8.1, U3.4 (AIN0)
unnamed: J9.1, R9.1, U3.5 (AIN1)
unnamed: J10.1, R10.1, U3.6 (AIN2)
unnamed: J11.1, R11.1, U3.7 (AIN3)

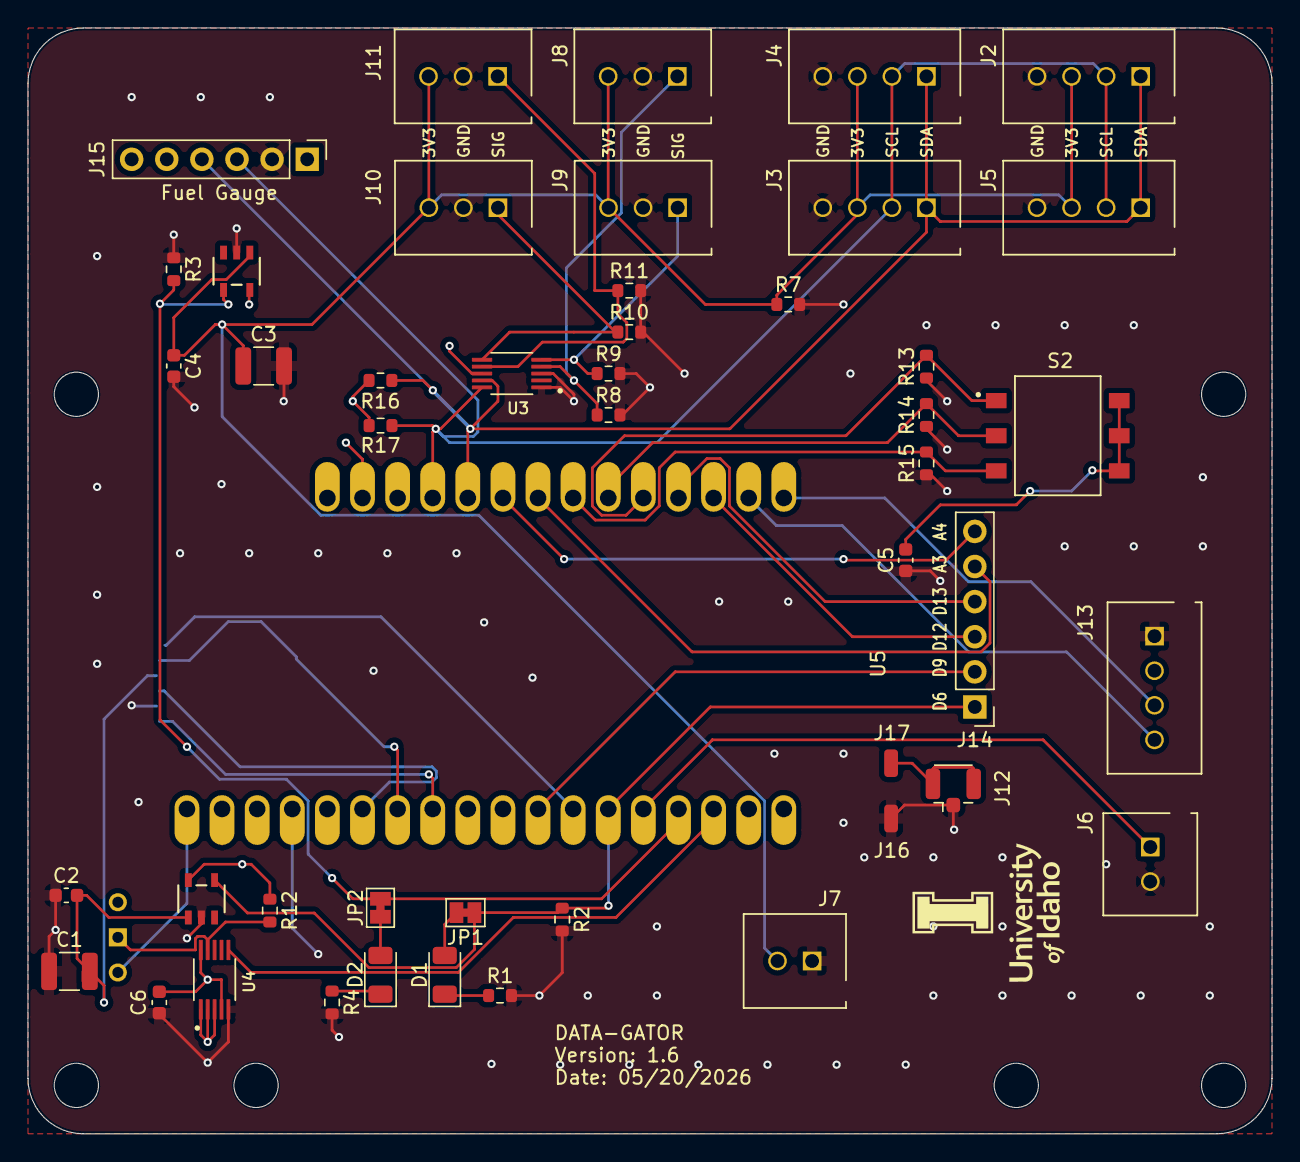
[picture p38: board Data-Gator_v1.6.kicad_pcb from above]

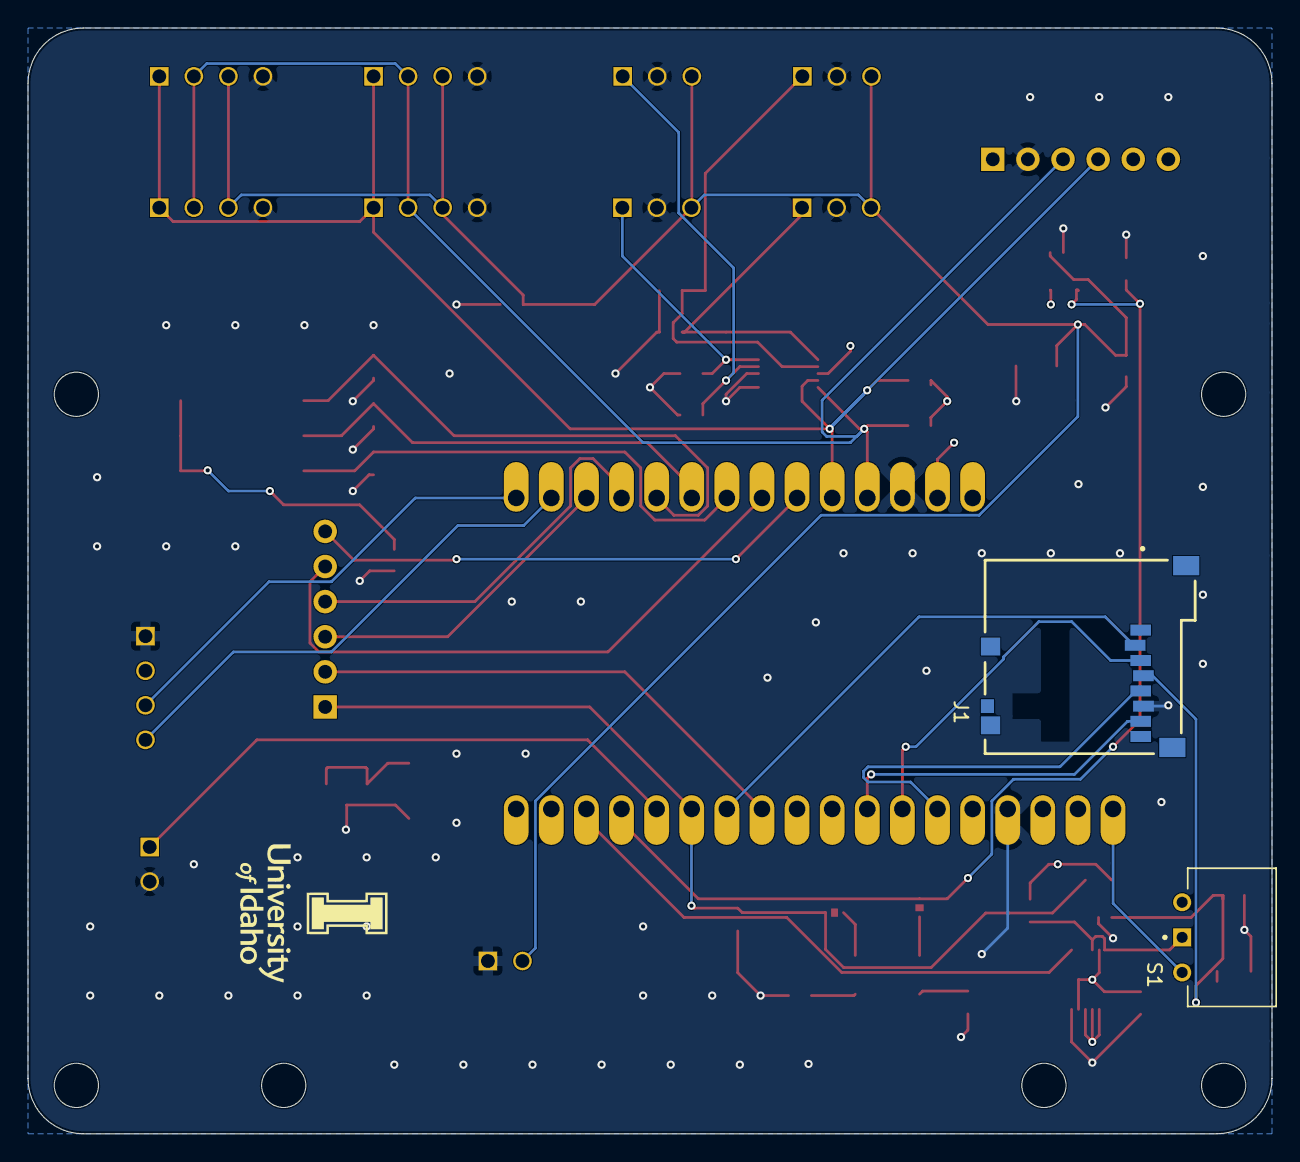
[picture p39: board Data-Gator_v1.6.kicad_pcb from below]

Board: 4 copper layers, 90.0 x 80.0 mm, 49 parts (2 on the bottom side), 35 nets.

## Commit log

2023-09-05 added board tour to readme
2023-09-05 added board assem docs
2023-09-15 added v0.1 jlcpcb assembly
2023-09-15 added notes and v1.5 gerber
2023-10-04 added prelim pcb assembly guide
2023-10-04 added antenna mod guide link
2023-10-07 added BOM
2023-10-25 added PCBWay files
    [Aggregator Schematic v315_top_bom.csv, updated quotation-T-2Y2W555747A-10sets-Aggregator+Schematic+v315_top_bom(2023-08-18).xls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]
2023-10-25 adding through hole and enclosure build guides
2023-10-25 added pcb through hole guide rename
2026-05-20 Added Data-Gator v1.6 design files
    [Analog.kicad_sch, Data-Gator_v1.6.kicad_pcb, Data-Gator_v1.6.kicad_sch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]
2026-05-20 Created Fabrication Files
    [Data-Gator_v1.6-B_Cu.gbl, Data-Gator_v1.6-B_Mask.gbs, Data-Gator_v1.6-B_Paste.gbp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]
2026-05-20 Separated design files by type
    [Data-Gator_v1.6-B_Cu.gbl, Data-Gator_v1.6-B_Mask.gbs, Data-Gator_v1.6-B_Paste.gbp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]
2026-05-20 KiCAD project files need saving when no changes made :(
    [Data-Gator_v1.6.kicad_pcb]
2026-05-20 Regenerated design files
    [Data-Gator_v1.6-B_Cu.gbl, Data-Gator_v1.6-B_Mask.gbs, Data-Gator_v1.6-B_Paste.gbp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]
